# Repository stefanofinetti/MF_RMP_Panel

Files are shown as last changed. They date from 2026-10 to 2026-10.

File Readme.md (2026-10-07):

# Radio Management Panel (RMP)

An Airbus A319/320/321 Radio Management Panel for MobiFlight: a 3D-printed
front panel, keys and case, four boards, and two 6-digit frequency displays.
It runs on the **stock MobiFlight Mega firmware**: no custom firmware to
build or flash.

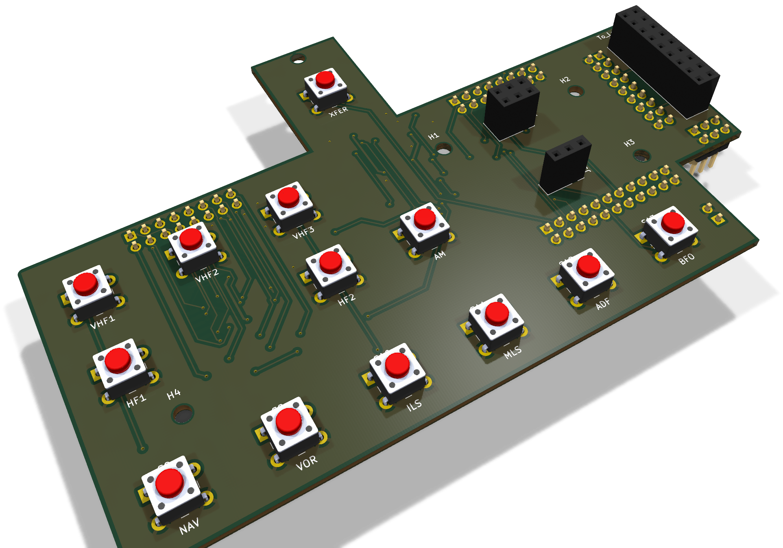
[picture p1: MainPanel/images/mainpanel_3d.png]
The MainPanel, rendered by KiCad


## V5 in short

V5 replaces the earlier version of this repository, a single board with
OLED displays and its own firmware. It is a new design:

* **four boards** instead of one: the logic, the keys and display drivers,
  the lighting, and a carrier for each frequency display;
* **7-segment displays** driven by two MAX7219, which MobiFlight drives
  natively as one LED module;
* **stock firmware**, MobiFlight Mega, core 3.1.4;
* the printed parts are drawn in **FreeCAD 1.1**.

**Status (October 2026):** the unit is built and in use. The boards in this
repository are the built ones, with one correction on the MainPanel (see
[Known issues](#known-issues)). All four are in KiCad 10, with ERC, DRC and
schematic parity clean. The printed parts are being reorganised.

## What is in the repository

| Folder | What it holds |
|---|---|
| [`BoardPanel/`](BoardPanel/README.md) | The logic board: ATmega2560, CH340G USB, 12 V and 5 V supply |
| [`MainPanel/`](MainPanel/README.md) | The keys, the two MAX7219, and the connectors to every other board |
| [`LedsPanel/`](LedsPanel/README.md) | The backlight and the thirteen key lights |
| [`7Segments/`](7Segments/README.md) | The carrier of one frequency display. Two are needed |
| `Libraries/` | The parts shared by the four boards: `RMP.kicad_sym`, `RMP.pretty` and the vendor 3D models in `3dmodels/` |
| `SF_RMP/` | `SF RMP.mfmc`, the MobiFlight board config |
| `3D FIles/` | The FreeCAD sources (`RMP_Panel.FCStd` is the whole assembly), the STL files, the B612 fonts of the legends. Being reorganised |

## The boards

```
 12 V jack ─► BoardPanel ─┬─ J4 ribbon ─► MainPanel J2 ─► J1 ─► LedsPanel (plugged in)
 USB-B     ─►             ├─ J5 ribbon ─► MainPanel J3   keys, encoders, ON/OFF
                          └─ J3 ribbon ─► MainPanel J9 ─┬─ J7 ribbon ─► 7Segments ACTIVE
                                                        └─ J8 ribbon ─► 7Segments STBY
```

| Board | PCB (mm) | What is on it |
|---|---|---|
| [BoardPanel](BoardPanel/README.md) | 110 × 55 | ATmega2560, CH340G, USB-B, 12 V jack, P78A05 5 V module, ISP header |
| [MainPanel](MainPanel/README.md) | 122 × 80 | 13 keys, 2 × MAX7219, encoder and switch connectors |
| [LedsPanel](LedsPanel/README.md) | 122 × 80 | 69 backlight LEDs with their PWM switch, 13 key lights |
| [7Segments](7Segments/README.md) × 2 | 51 × 20 | Two 3-digit common-cathode displays, MHz and kHz |

All four are two-layer, 1.6 mm boards, sized for hand soldering, with
values, polarity and pin 1 on the silkscreen.

## Building one

1. **Print** the panel, keys, case and supports from `3D FIles/`.
2. **Order the boards.** Run the Fabrication Toolkit plugin in each KiCad
   project for the Gerbers, BOM and positions. Order the 7Segments twice.
3. **Assemble** them. The board readmes list what to watch for.
4. **Cable them** as in the diagram above: straight ribbons, pin 1 to
   pin 1. The LedsPanel plugs straight into the MainPanel's J1.
5. **Burn the bootloader** once through the ISP header J2 of the BoardPanel,
   with JP1 on 2–3; then put JP1 back on 1–2. See the
   [BoardPanel readme](BoardPanel/README.md#burning-the-bootloader).
6. **Flash the MobiFlight Mega firmware** from the MobiFlight Connector,
   then load `SF_RMP/SF RMP.mfmc` and upload it to the board.
7. **Bind** the keys, lights, displays and encoders in your MobiFlight
   project.

The BoardPanel's logic runs from USB; the 12 V adapter feeds the backlight,
the displays and the fan.

## MobiFlight

Stock **MobiFlight Mega** firmware, module name `SF RMP`. The config in
`SF_RMP/SF RMP.mfmc` holds:

| Device | Type | Pins |
|---|---|---|
| `Display Freq` | LED module, MAX7219, 2 devices | DIN D23, CLK D22, CS D68. Connector 1 = STBY, connector 2 = ACTIVE |
| `Dimmer` | Output, PWM | D6, the backlight |
| `KHZ_Encoder` | Encoder | Left D27, right D25 |
| `MHZ_Encoder` | Encoder | Left D28, right D26 |
| `VHF1_LED` … `SEL_LED` | Outputs | A0–A12 (D54–D66): VHF1, VHF2, VHF3, HF1, HF2, AM, NAV, VOR, ILS, MLS, ADF, BFO, SEL |

| Key | Pin | Key | Pin | Key | Pin |
|---|---|---|---|---|---|
| XFER | D29 | HF2 | D36 | MLS | D31 |
| VHF1 | D39 | AM | D35 | ADF | D30 |
| VHF2 | D15 | NAV | D34 | BFO | D40 |
| VHF3 | D14 | VOR | D33 | ON/OFF | D41 |
| HF1 | D37 | ILS | D32 | | |

Each MAX7219 drives six digits; the decimal point after the MHz is set in
the project row of each display.

## Known issues

* **The first MainPanel had the two MAX7219 side by side instead of in a
  chain.** The files here are corrected. A board built from the first files
  needs two wires, described in the
  [MainPanel readme](MainPanel/README.md#boards-built-before-this-revision).
* **Two STL files are empty:** the white parts of the VHF1 and VHF3 keys.
  They will be re-exported from FreeCAD with the reorganisation of the
  printed parts.

## Software

* [KiCad](https://www.kicad.org/) 10. The files are saved by KiCad 10 and
  do not open in older versions
* [FreeCAD](https://www.freecad.org/) 1.1, to change the printed parts
* [MobiFlight](https://www.mobiflight.com/)

```bash
git clone https://github.com/stefanofinetti/MF_RMP_Panel.git
```

## License

This code and all the items are released under the GPLv3.0 license. Feel free
to use them as you wish, as long as you redistribute the source code.
A mention would be nice, though, if you use this work: I invested a good
many hours in it, just for the amazing MobiFlight community.

## Acknowledgements

This project couldn't have seen the light without the excellent work, and
kind support, of [GaGagu](https://github.com/gagagu) and
[ElRal](https://github.com/elral). Their work is amazing, so please have a
look at their repositories.

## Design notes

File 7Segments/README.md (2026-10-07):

# RMP 7Segments

The carrier of one frequency display: two 3-digit 7-segment displays,
MHz and kHz, side by side. **Two are needed**, one for ACTIVE and one for
STBY. Each sits in its printed display case and reaches the MainPanel
through a 16-pin ribbon.

* **PCB:** 51 × 20 mm, 2 layers, 1.6 mm, GND poured on both sides.
* **Fixing:** six M2 holes.
* **Parts:** 5: four socket strips for the displays on the top, one header
  on the bottom.
* **Status:** built and in use. ERC and schematic parity are clean; DRC
  reports only silkscreen clipped by the solder mask around J5.

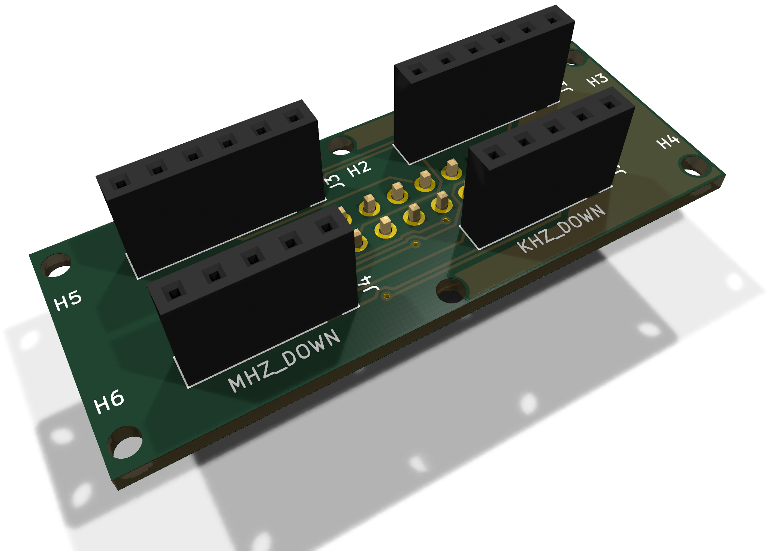
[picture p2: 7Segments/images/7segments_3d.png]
7Segments, 3D view


| Top: the display sockets | Bottom: J5 |
|---|---|
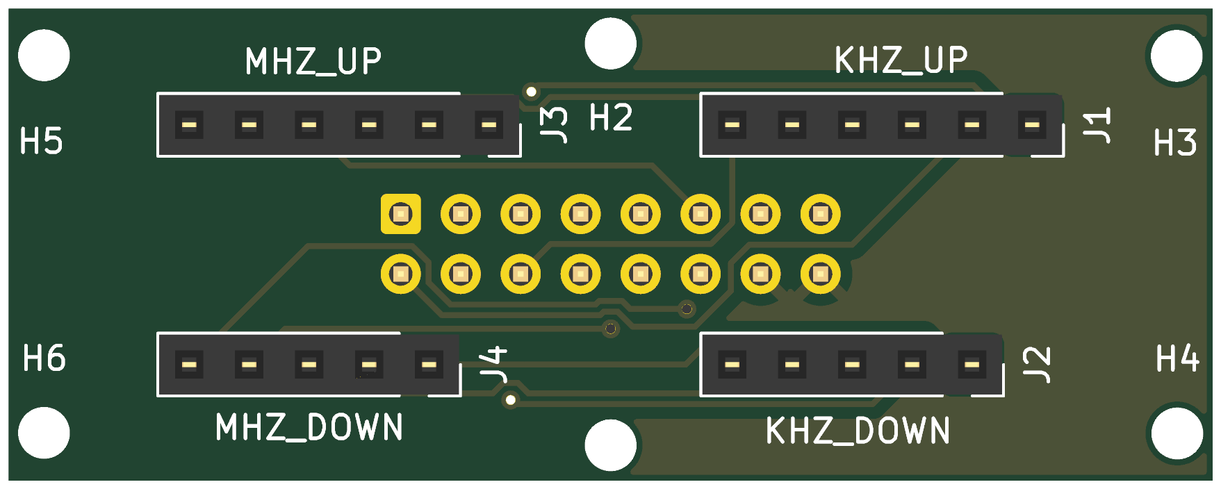
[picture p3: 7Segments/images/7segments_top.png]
7Segments, top
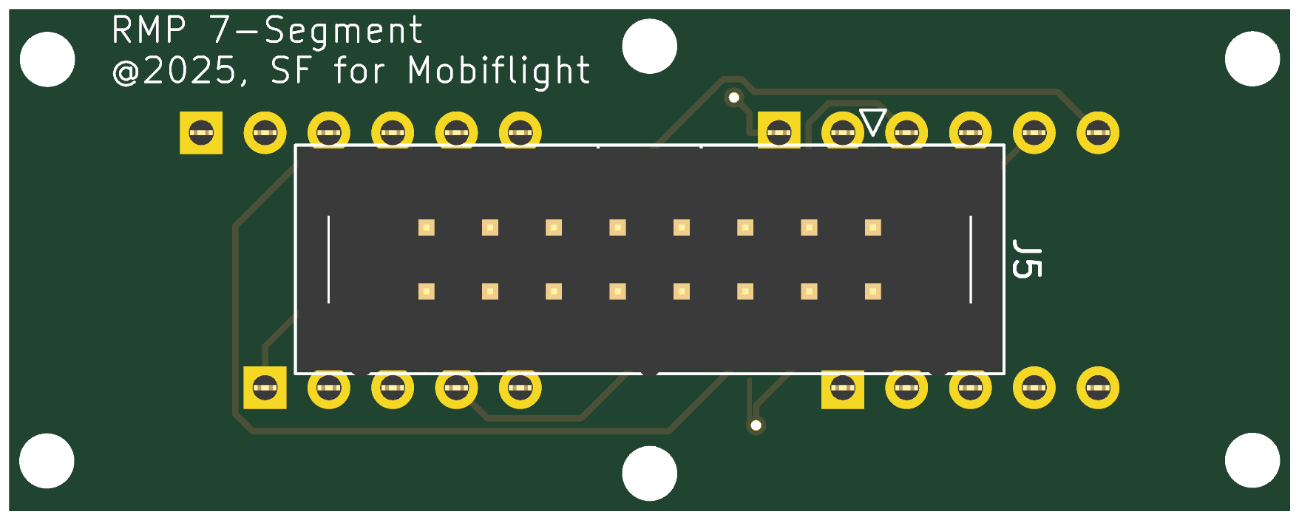
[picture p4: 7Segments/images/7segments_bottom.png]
7Segments, bottom
|  |  |

Rendered by KiCad from the board file. The bottom is seen from below, so it
is mirrored against the top.

## Connectors

| Ref | What | Notes |
|---|---|---|
| J1 / J2 | Socket strips 1 × 6 / 1 × 5 | kHz display, upper and lower row of pins |
| J3 / J4 | Socket strips 1 × 6 / 1 × 5 | MHz display, upper and lower row of pins |
| J5 | Shrouded IDC header 2 × 8, on the bottom | To MainPanel J7 (ACTIVE) or J8 (STBY), pin 1 to pin 1 |

**J5:** odd pins are the segments, 1 A, 3 B, 5 C, 7 D, 9 E, 11 F, 13 G,
15 the decimal point; even pins are the digits, 2 / 4 / 6 kHz 3 / 2 / 1,
8 / 10 / 12 MHz 3 / 2 / 1; 14 and 16 GND.

The displays must be **common cathode**: the MAX7219 sinks the digits and
drives the segments. The decimal point is wired on both displays; which digit
shows it is set in the MobiFlight project.

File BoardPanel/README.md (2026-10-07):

# RMP BoardPanel

The logic board of the RMP: the microcontroller, USB and power. It stands
upright on the printed support at the back of the case and reaches the
MainPanel through three ribbons.

* **PCB:** 110 × 55 mm, 2 layers, 1.6 mm, GND poured on both sides.
* **Fixing:** six M2 holes.
* **Parts:** 44, all on the top.
* **Status:** built and in use. ERC, DRC and schematic parity are clean.

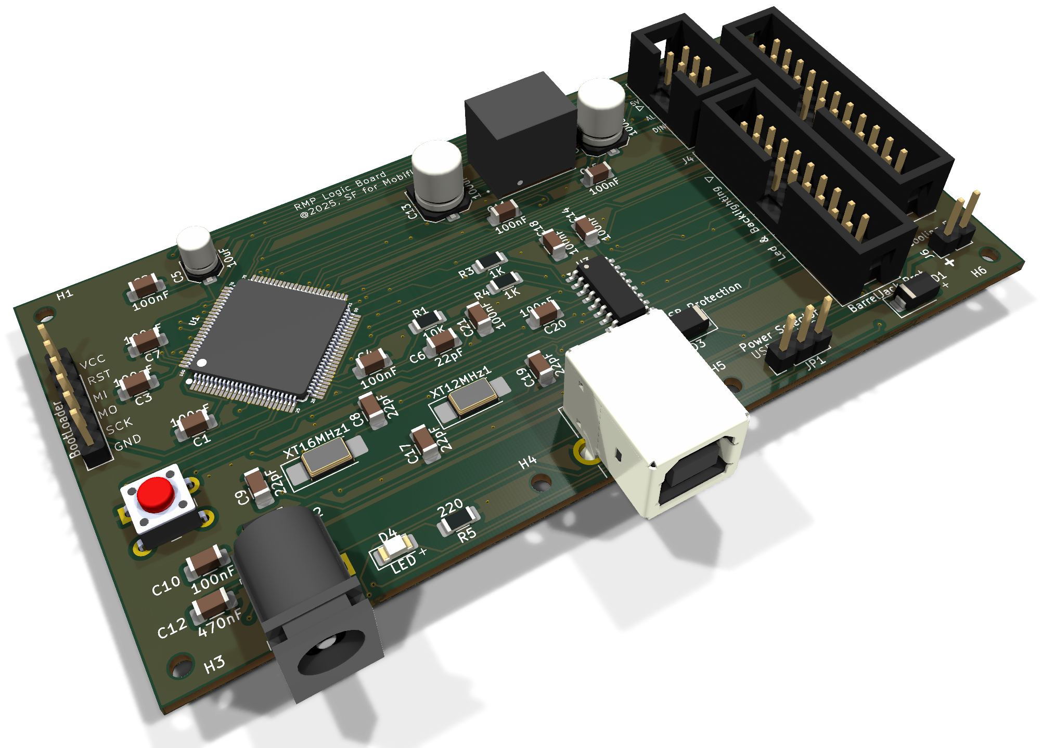
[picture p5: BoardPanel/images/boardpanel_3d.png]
BoardPanel, 3D view


| Top | Bottom |
|---|---|
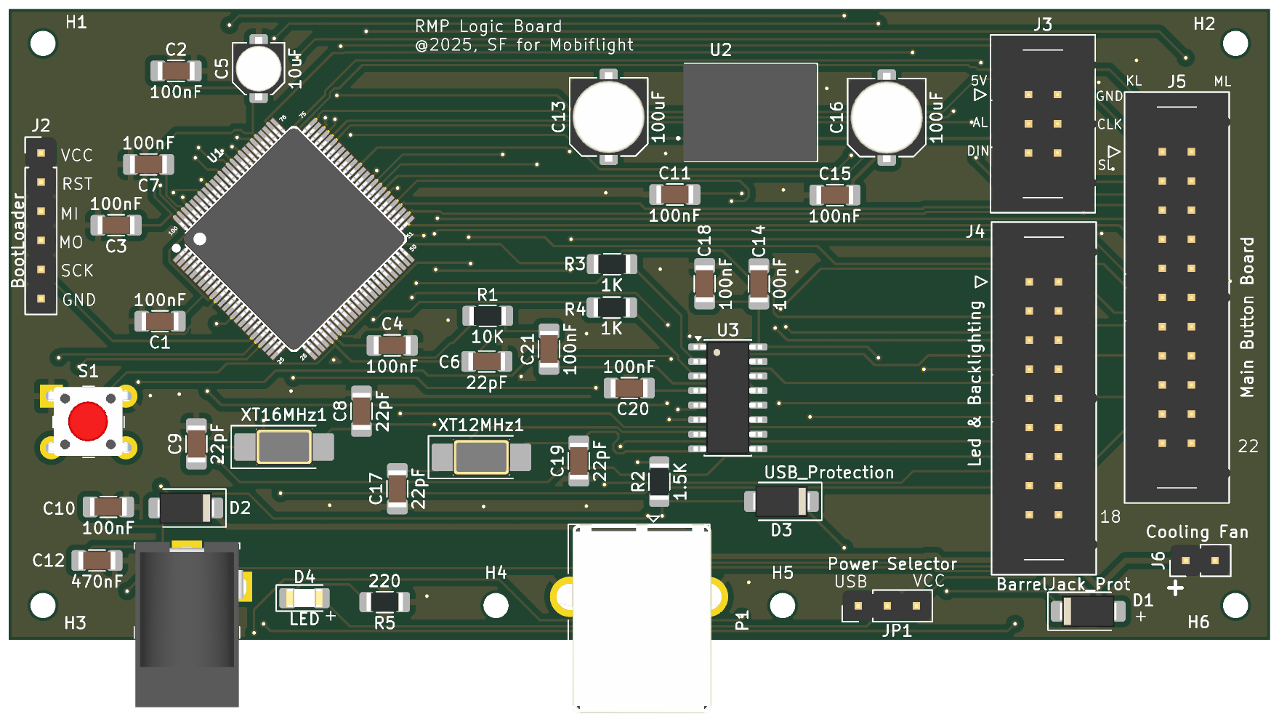
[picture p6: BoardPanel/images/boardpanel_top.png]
BoardPanel, top
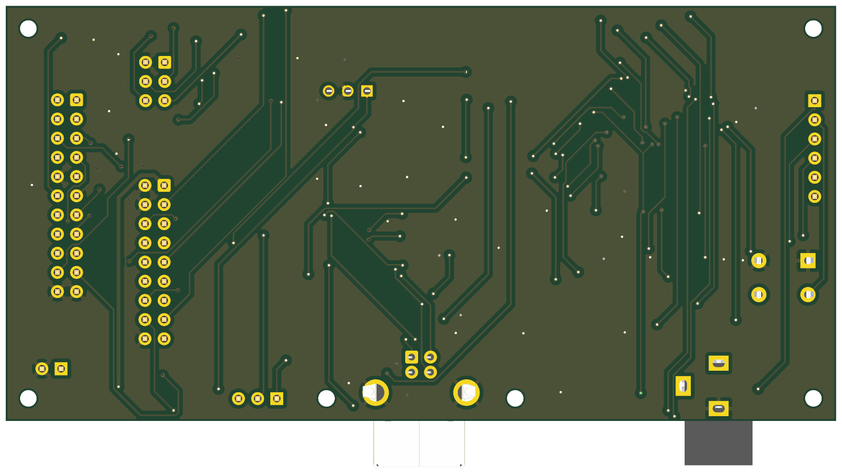
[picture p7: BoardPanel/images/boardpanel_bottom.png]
BoardPanel, bottom
|  |  |

Rendered by KiCad from the board file. The bottom is seen from below, so it
is mirrored against the top.

## What is on it

* **Microcontroller:** ATmega2560 (U1) with a 16 MHz crystal, and a CH340G
  (U3, 12 MHz crystal) for USB. MobiFlight sees it as a Mega.
* **Power:**
  * 12 V from the barrel jack J1, through D2, is the `+12V` rail: the
    backlight (J4) and the fan (J6).
  * From `+12V`, through D1, a P78A05 switching module (U2) makes the 5 V
    for the two MAX7219 only (J3).
  * The ATmega and the CH340G run from USB, through D3 and JP1. The
    displays and the backlight need the 12 V; the logic does not.

## Connectors and settings

| Ref | What | Notes |
|---|---|---|
| J1 | 12 V in, 5.5 × 2.1 barrel jack | Pin 1 `+`, through D2 |
| P1 | USB-B | To the computer |
| J2 | ISP header, 1 × 6 | 1 VCC, 2 RESET, 3 MISO, 4 MOSI, 5 SCK, 6 GND |
| JP1 | Power selector | 1–2: MCU from USB (normal use). 2–3: MCU from J2's VCC only, to burn the bootloader |
| J3 | Displays, IDC 2 × 3 | To MainPanel J9 |
| J4 | LEDs and backlight, IDC 2 × 9 | To MainPanel J2 |
| J5 | Buttons and encoders, IDC 2 × 11 | To MainPanel J3 |
| J6 | Cooling fan, 2 pins | `+12V` and GND, for a 12 V fan |
| S1 | Reset | |

Every ribbon is straight, pin 1 to pin 1.

**J3, displays:** 1 `+5V`, 2 GND, 3 D67 (marked `AL`, no longer used, see
the MainPanel), 4 CLK (D22), 5 DIN (D23), 6 LOAD (D68).

**J4, LEDs and backlight:** 1 `+12V`, 2 GND, 3 backlight PWM (D6), 4 GND,
5–17 the thirteen key LEDs (A0–A12, in the order VHF1, VHF2, VHF3, HF1,
HF2, AM, NAV, VOR, ILS, MLS, ADF, BFO, SEL), 18 GND.

**J5, buttons and encoders:** see the pin map in the
[main readme](../Readme.md#mobiflight).

## Burning the bootloader

A new ATmega2560 is blank. Put JP1 on 2–3, so the programmer powers the
MCU alone through J2, and burn the Arduino Mega bootloader once. Then put
JP1 back on 1–2. From then on the board is flashed over USB like a Mega.

## Assembly notes

* Everything is sized for hand soldering: 1206 passives, 5 × 3.2 mm
  crystals.
* Values, polarity and pin 1 are on the silkscreen.

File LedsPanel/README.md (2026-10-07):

# RMP LedsPanel

The lighting board, right behind the front panel: the backlight of the
legends and the thirteen key lights. It plugs straight into the MainPanel.

* **PCB:** 122 × 80 mm, 2 layers, 1.6 mm, GND poured on both sides.
* **Fixing:** six M2.5 holes.
* **Parts:** 113. The backlight resistors and J1 are on the bottom.
* **Status:** built and in use. ERC, DRC and schematic parity are clean.

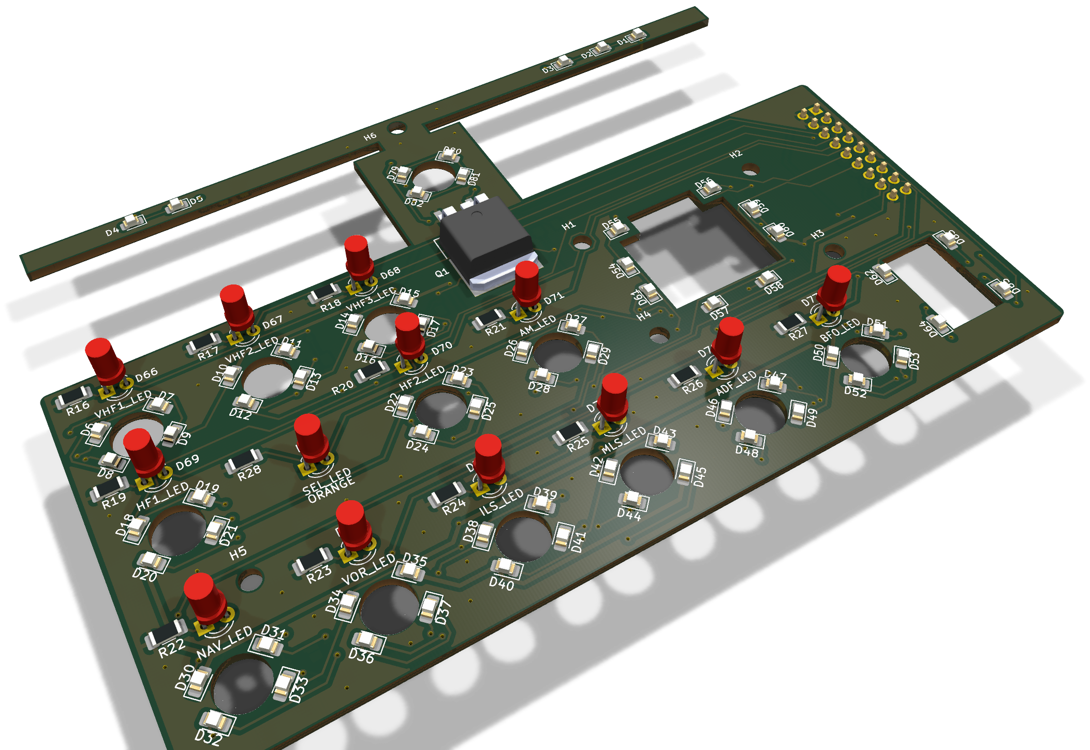
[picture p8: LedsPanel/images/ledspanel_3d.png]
LedsPanel, 3D view


| Top: the panel side | Bottom: resistors and J1 |
|---|---|
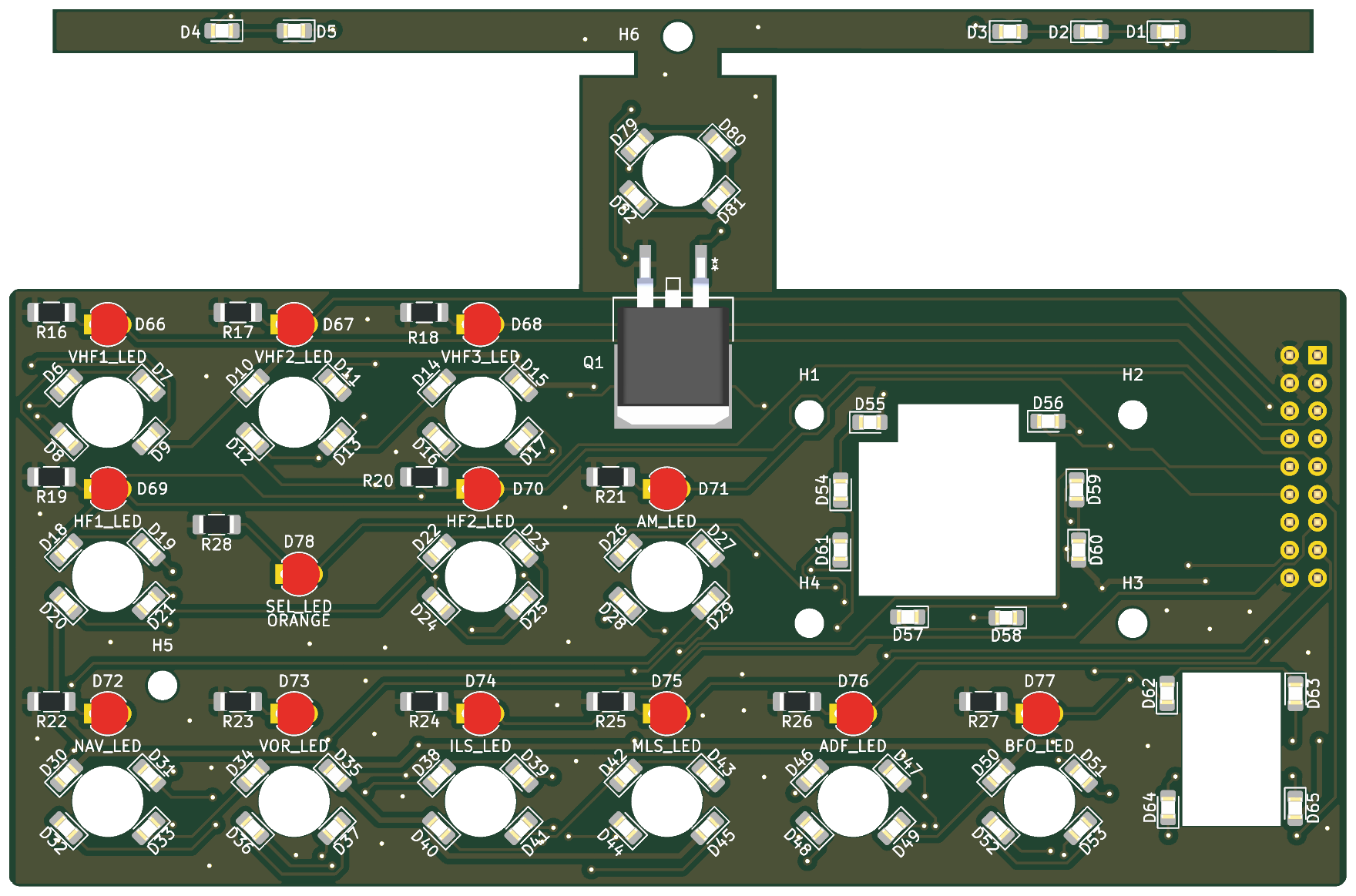
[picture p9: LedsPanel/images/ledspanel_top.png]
LedsPanel, top
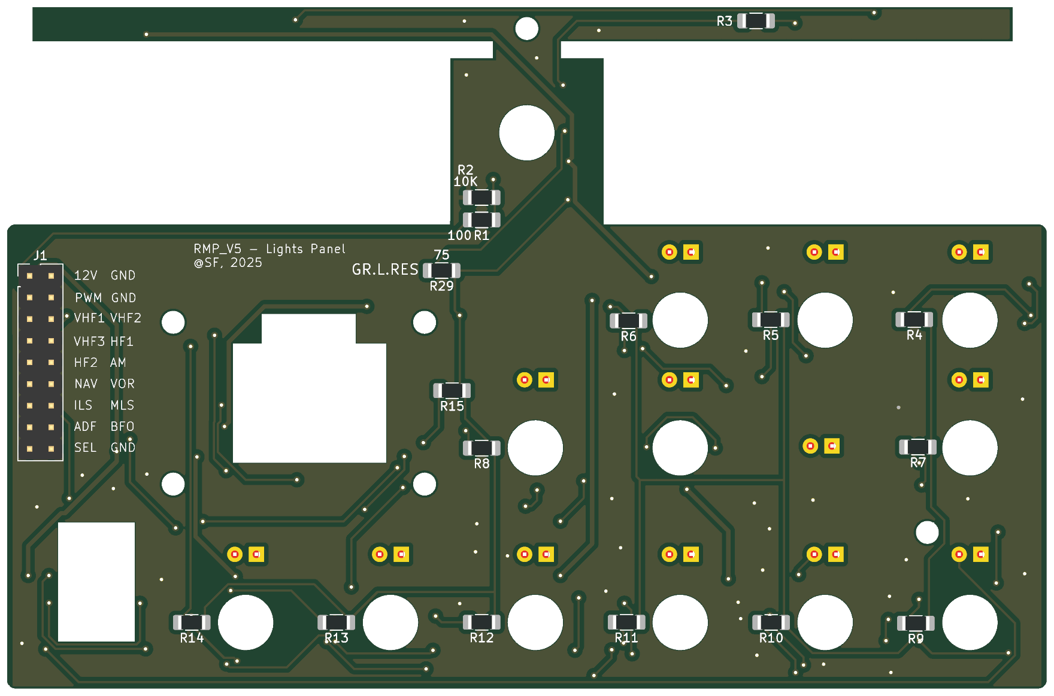
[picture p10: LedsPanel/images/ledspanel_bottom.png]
LedsPanel, bottom
|  |  |

Rendered by KiCad from the board file. The bottom is seen from below, so it
is mirrored against the top.

## Connector

| Ref | What | Goes to |
|---|---|---|
| J1 | Header 2 × 9, on the bottom | Plugs into the MainPanel's J1. 1 `+12V`, 2 / 4 / 18 GND, 3 backlight PWM, 5–17 the key LEDs |

## Backlight

69 orange 0805 LEDs, chosen to match the brightness of the Airbus panels,
on `+12V`:

* D1–D65: thirteen strings of five, each with its 75 Ω (R3–R15);
* D79–D82: one string of four, with R29, 75 Ω.

Every string returns to `LED_RETURN`, switched to GND by Q1, an IRLZ44N
(logic-level N-MOSFET, D2PAK). Its gate is driven by the backlight PWM
(D6) through R1, 100 Ω, with R2, 10 kΩ, pulling it down: with the PWM at 0
or the MobiFlight Connector closed, the backlight is off.

The string of four has one LED fewer across the same 75 Ω, so it carries
more current than the strings of five.

## Key lights

D66–D78, 3 mm flat-top LEDs, one in each key. The anode is driven straight
by the MCU pin through J1; the cathode goes to GND through 200 Ω
(R16–R28).

| D66 | D67 | D68 | D69 | D70 | D71 | D72 | D73 | D74 | D75 | D76 | D77 | D78 |
|---|---|---|---|---|---|---|---|---|---|---|---|---|
| VHF1 | VHF2 | VHF3 | HF1 | HF2 | AM | NAV | VOR | ILS | MLS | ADF | BFO | SEL |

The key lights are not dimmed. On the aircraft they follow the ANN LT
switch, apart from the backlight; a separate dimmer for them is being
considered.

## Assembly notes

* Everything is sized for hand soldering: 0805 LEDs, 1206 resistors.
* LED polarity, values and pin 1 are on the silkscreen.

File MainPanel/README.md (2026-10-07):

# RMP MainPanel

The board behind the front panel: the thirteen keys, the two MAX7219 that
drive the frequency displays, and the connectors for the encoders, the
ON/OFF switch, the LedsPanel and the two display boards. It reaches the
BoardPanel through three ribbons.

* **PCB:** 122 × 80 mm, 2 layers, 1.6 mm, GND poured on both sides.
* **Fixing:** five 2.5 mm holes.
* **Parts:** 30. On the top: the keys, J1 for the LedsPanel and the two
  encoder sockets. On the bottom: the two MAX7219 with their passives, and
  the headers to the BoardPanel, the display boards and the ON/OFF switch.
* **Status:** the display chain is corrected in this revision (see below)
  and rerouted. ERC, DRC and schematic parity are clean. The corrected
  board has not been ordered yet.

MainPanel, 3D view

| Top: the keys | Bottom: drivers and connectors |
|---|---|
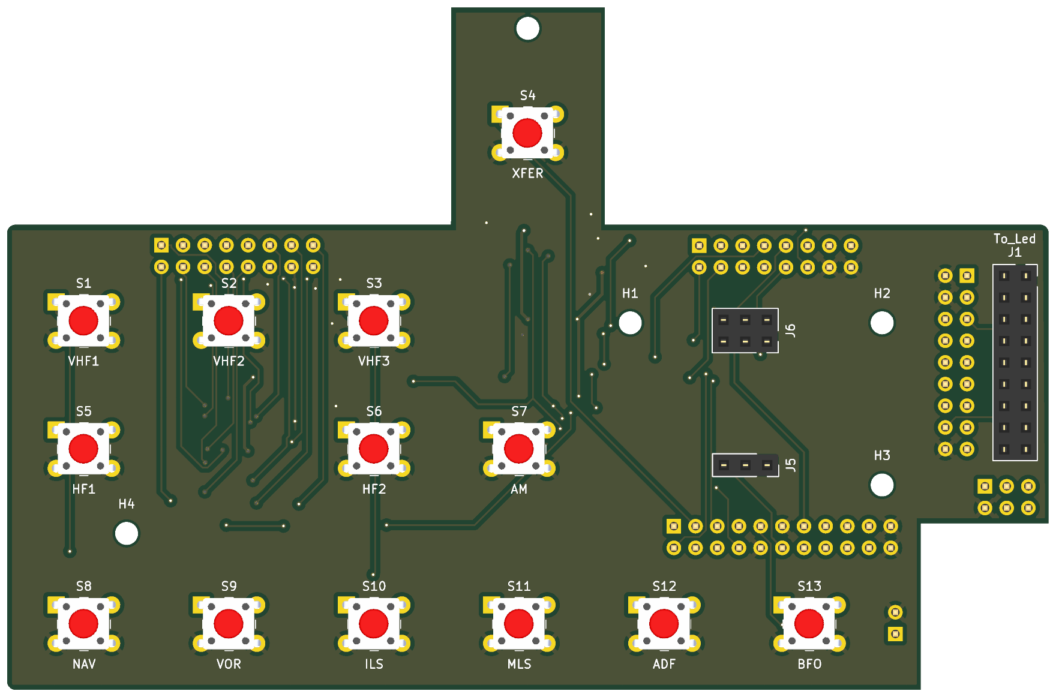
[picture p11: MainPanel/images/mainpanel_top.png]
MainPanel, top
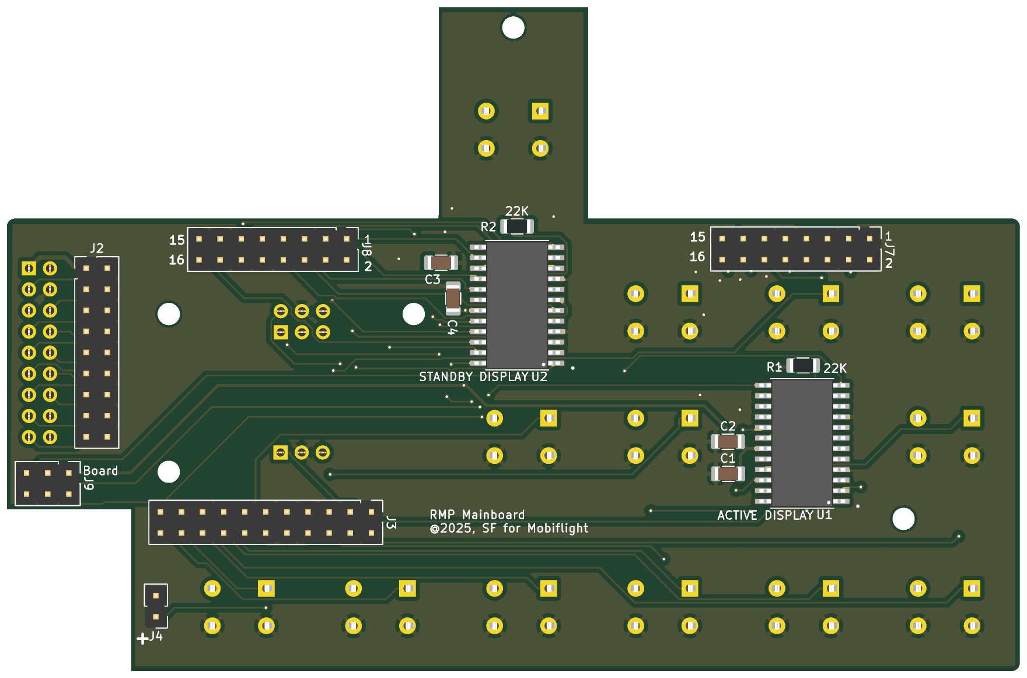
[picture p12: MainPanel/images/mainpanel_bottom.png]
MainPanel, bottom
|  |  |

Rendered by KiCad from the board file. The bottom is seen from below, so it
is mirrored against the top.

## Connectors

| Ref | What | Goes to |
|---|---|---|
| J1 | Socket 2 × 9 | The LedsPanel's J1 plugs in here. Same pins as J2 |
| J2 | Header 2 × 9 | BoardPanel J4: backlight, PWM, the thirteen key LEDs |
| J3 | Header 2 × 11 | BoardPanel J5: keys, encoders, ON/OFF |
| J9 | Header 2 × 3 | BoardPanel J3: the display bus |
| J7 | Header 2 × 8 | ACTIVE display board, its J5 |
| J8 | Header 2 × 8 | STBY display board, its J5 |
| J5 | Socket 1 × 3 | kHz encoder: 1 `RADIO_KHZ_LEFT` (D25), 2 GND, 3 `RADIO_KHZ_RIGHT` (D27) |
| J6 | Socket 2 × 3 | MHz encoder: 2 `RADIO_MHZ_LEFT` (D26), 4 GND, 6 `RADIO_MHZ_RIGHT` (D28). Pins 1, 3, 5 are not connected |
| J4 | Header 1 × 2 | ON/OFF switch: 1 to D41, 2 GND |

Every connection is pin 1 to pin 1. The pinouts of J2, J3 and J9 are in
the [BoardPanel readme](../BoardPanel/README.md#connectors-and-settings).

## The keys

S1–S13, 6 × 6 mm tactile switches, each between its input and GND. The
MCU's internal pull-ups hold the inputs high.

| S1 | S2 | S3 | S4 | S5 | S6 | S7 | S8 | S9 | S10 | S11 | S12 | S13 |
|---|---|---|---|---|---|---|---|---|---|---|---|---|
| VHF1 | VHF2 | VHF3 | XFER | HF1 | HF2 | AM | NAV | VOR | ILS | MLS | ADF | BFO |

## The displays

Two MAX7219 in one chain, as MobiFlight expects for one LED module of two
devices:

```
D23 (DIN) ─► U2 STBY ─► DOUT ─► U1 ACTIVE
D22 (CLK) ─► U1 and U2
D68 (LOAD) ─► U1 and U2
```

U2 is the first device in the chain, so in MobiFlight connector 1 is the
standby frequency and connector 2 the active one. Each chip drives six
digits, three for MHz and three for kHz, through J7 / J8 to its display
board. R1 and R2 (22 kΩ) on `ISET` set the segment current; C1–C4 decouple
the two chips.

### Boards built before this revision

The first MainPanel had the two chips side by side on D23, with a LOAD
each (D67 for the Active, D68 for the Standby), and nothing on either
DOUT. That board works only with two hand-soldered wires, on the bottom:

1. pin 12 (LOAD) of U1 to pin 12 of U2;
2. pin 24 (DOUT) of U2 to pin 1 (DIN) of U1.

In the production files of that board, U1's pin 1 is also tied to D23 by
copper, which with the second wire gives it two drivers. If the Active
display shows the odd wrong segment now and then, check with the power off
for continuity between pin 1 of U1 and pin 1 of U2. If there is, cut the
track close to U1 pin 1.

## Assembly notes

* Everything is sized for hand soldering: 1206 passives, SOIC-24W chips.
* Values, polarity and pin 1 are on the silkscreen.

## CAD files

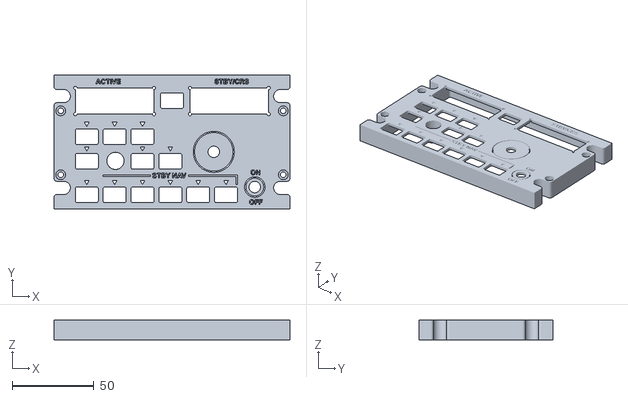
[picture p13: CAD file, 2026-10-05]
3D FIles/V5.1/RMP_Panel-Main Panel.stl
144.0 x 82.0 x 12.0

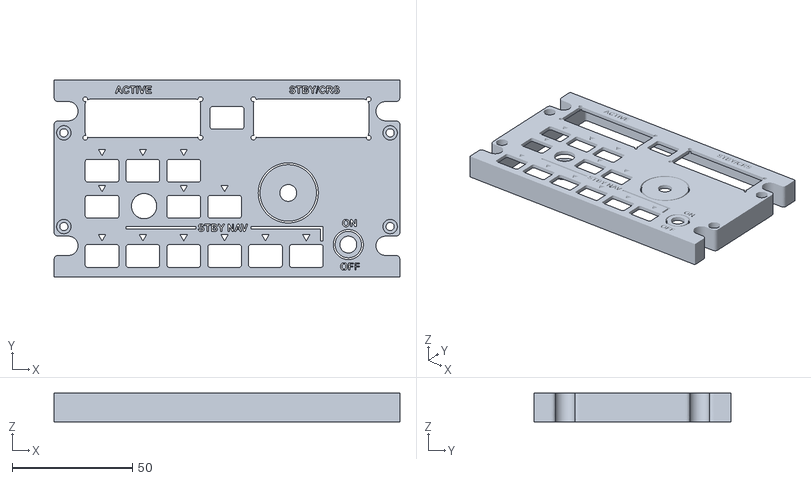
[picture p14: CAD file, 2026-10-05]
3D FIles/RMP_Panel-Main Panel.stl
144.0 x 82.0 x 12.0

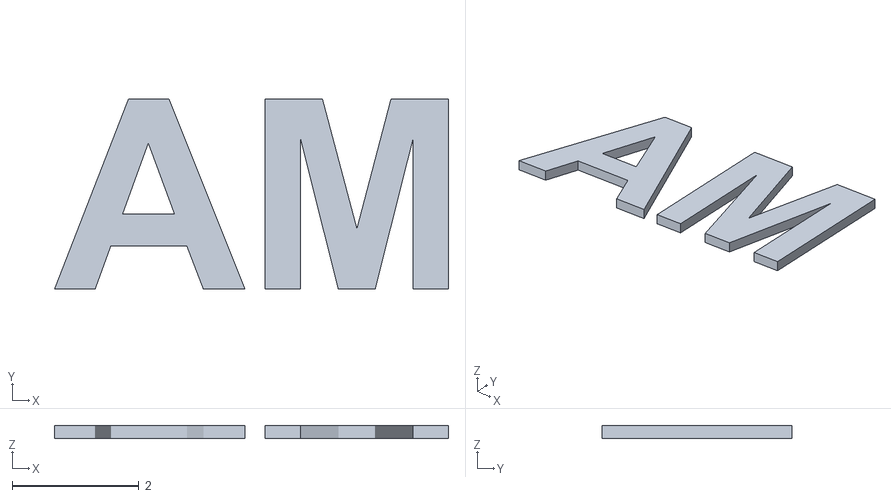
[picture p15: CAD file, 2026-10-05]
3D FIles/Buttons/RMP_Button-AM WhiteParts.stl
6.22 x 3.00 x 0.2

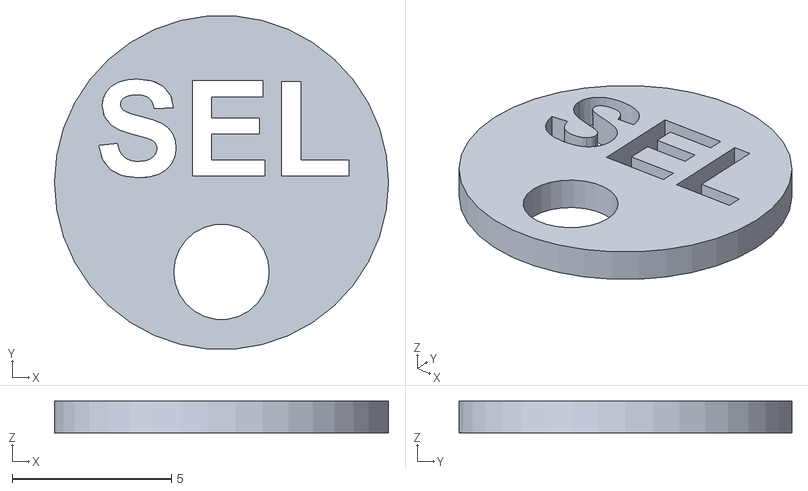
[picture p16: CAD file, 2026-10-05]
3D FIles/RMP_Panel-BlackElements.stl
10.5 x 10.5 x 1.00

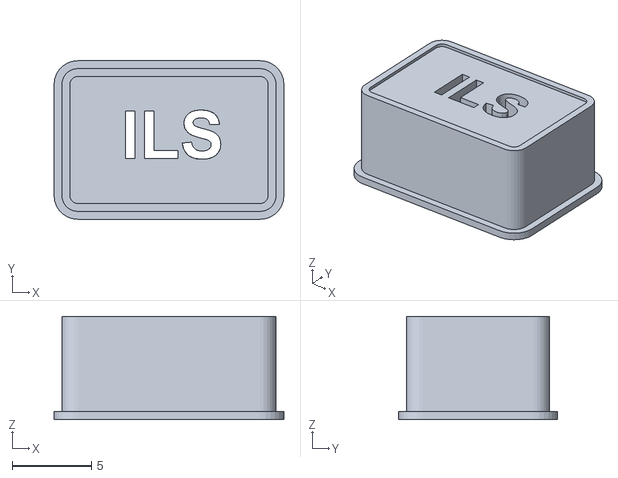
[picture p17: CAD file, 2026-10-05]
3D FIles/Buttons/RMP_Button-ILS Black Parts.stl
14.5 x 10.0 x 6.50

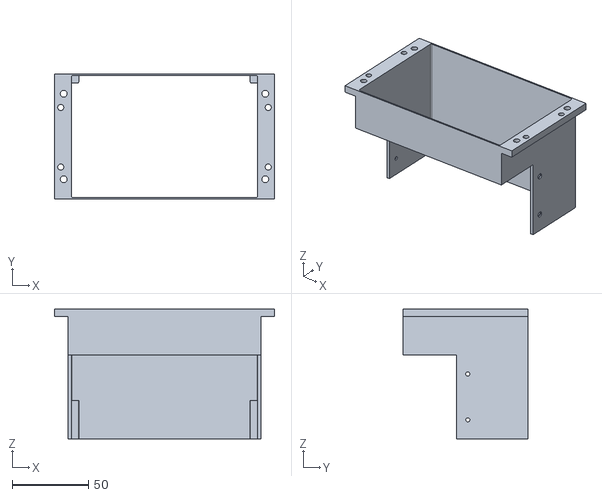
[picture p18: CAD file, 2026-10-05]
3D FIles/RMP_Panel-RMP Case.stl
144.0 x 82.0 x 85.0

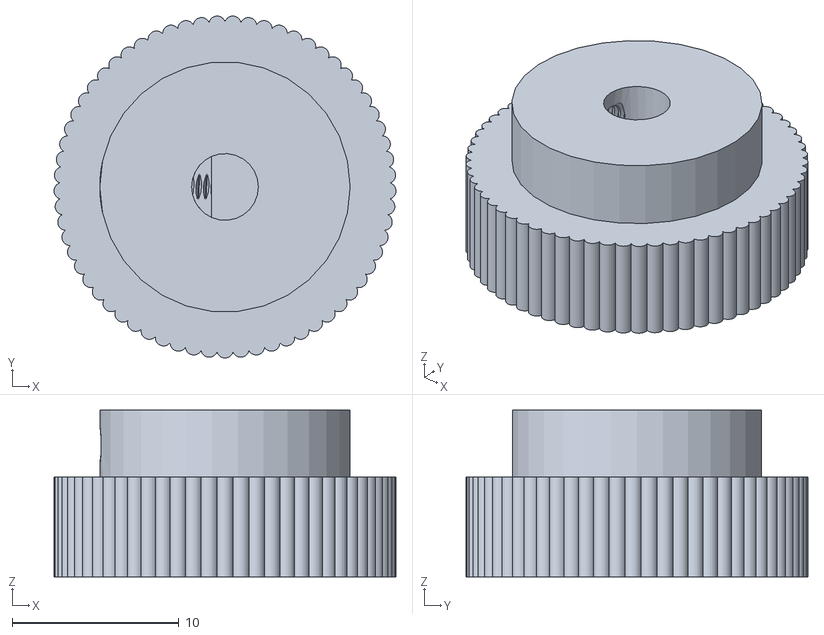
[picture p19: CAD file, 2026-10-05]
3D FIles/V5.1/RMP_Knob-UpperCircle_MHz.stl
20.5 x 20.5 x 10.0

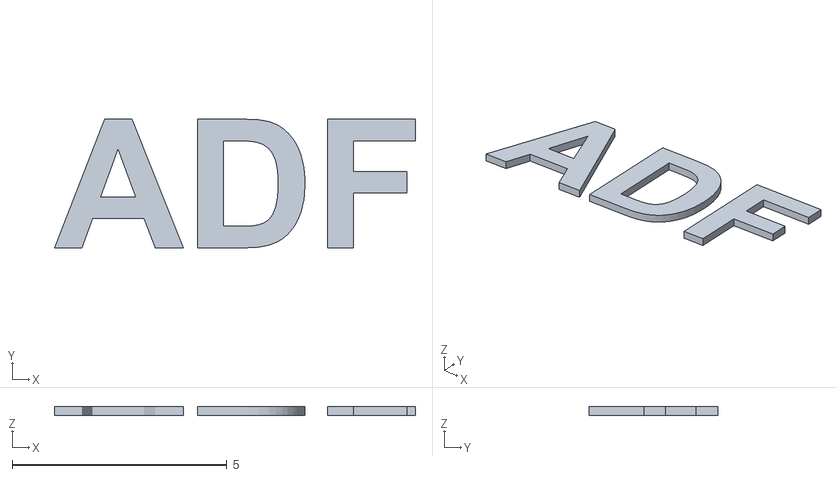
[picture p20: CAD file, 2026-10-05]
3D FIles/Buttons/RMP_Button- ADF White Parts.stl
8.42 x 3.00 x 0.2

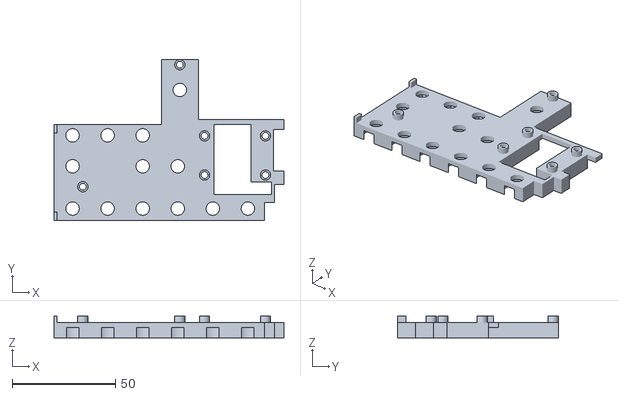
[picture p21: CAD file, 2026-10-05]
3D FIles/RMP_Panel-PCB Separator.stl
111.5 x 78.0 x 10.5

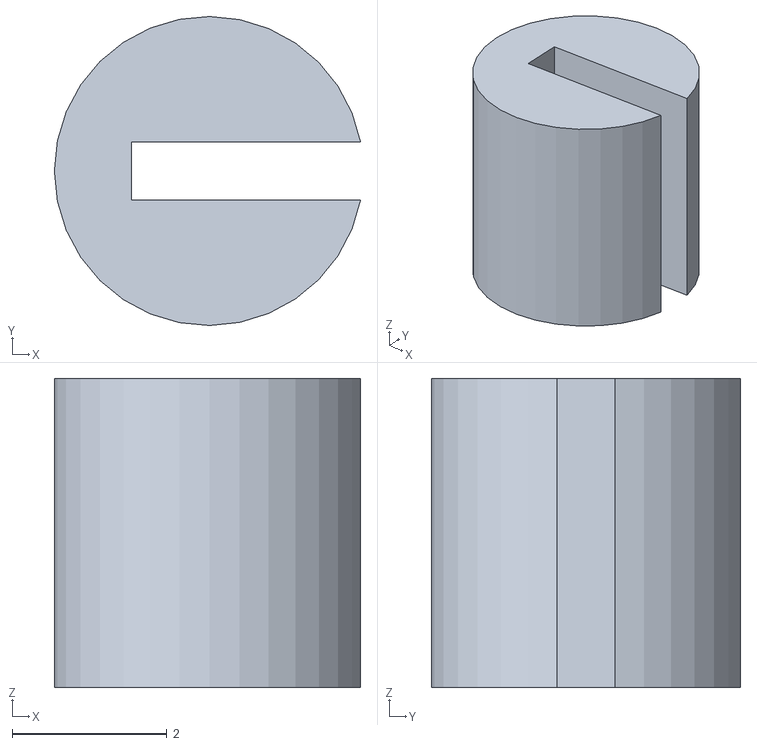
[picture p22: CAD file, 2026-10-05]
3D FIles/V5.1/CopriLed-CopriLed.stl
3.96 x 4.00 x 4.00

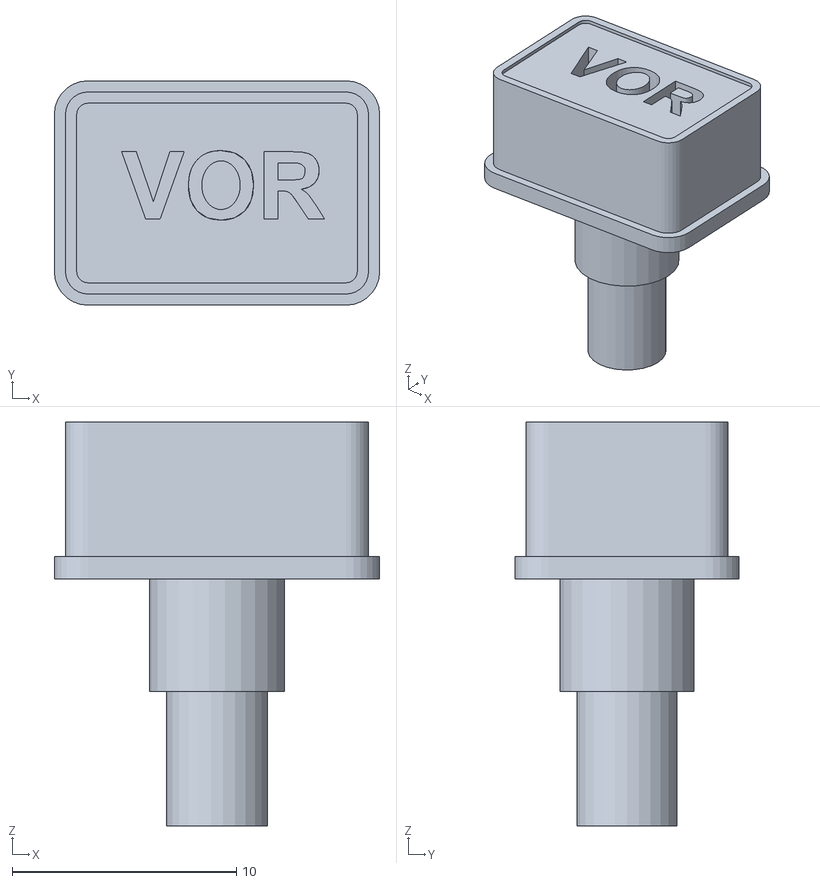
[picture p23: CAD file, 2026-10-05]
3D FIles/Buttons/RMP_Button- VOR Black Parts.stl
14.5 x 10.0 x 18.0

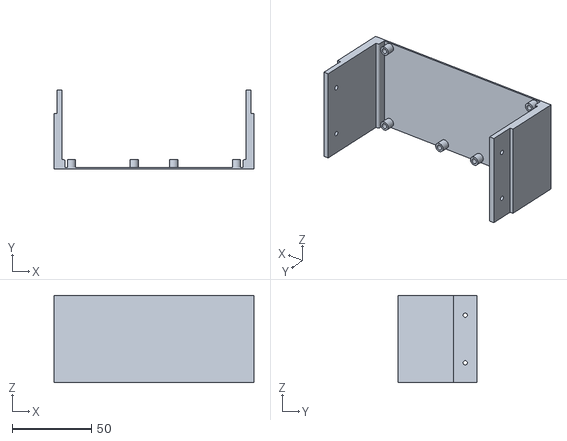
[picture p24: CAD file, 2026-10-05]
3D FIles/RMP_Panel-ArduinoSupport.stl
126.0 x 50.0 x 55.0

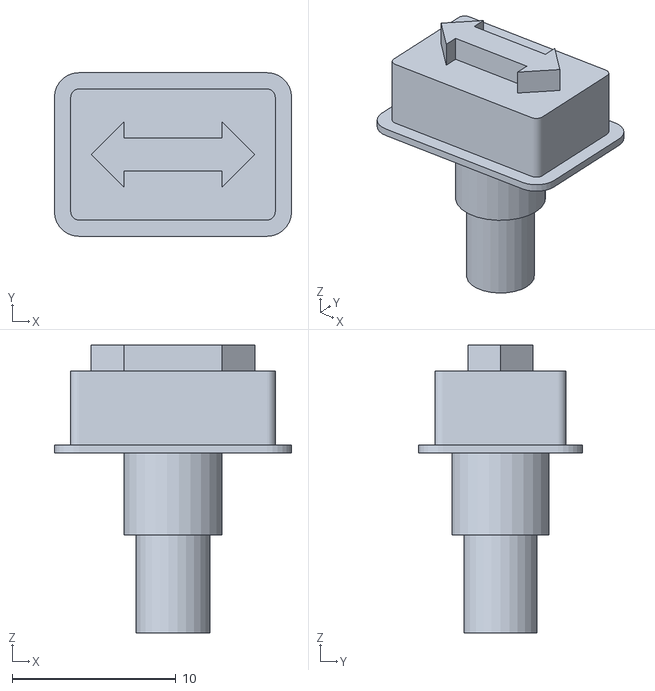
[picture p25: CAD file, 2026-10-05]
3D FIles/Buttons/RMP_Button-XFER Transparent Parts.stl
14.5 x 10.0 x 17.6

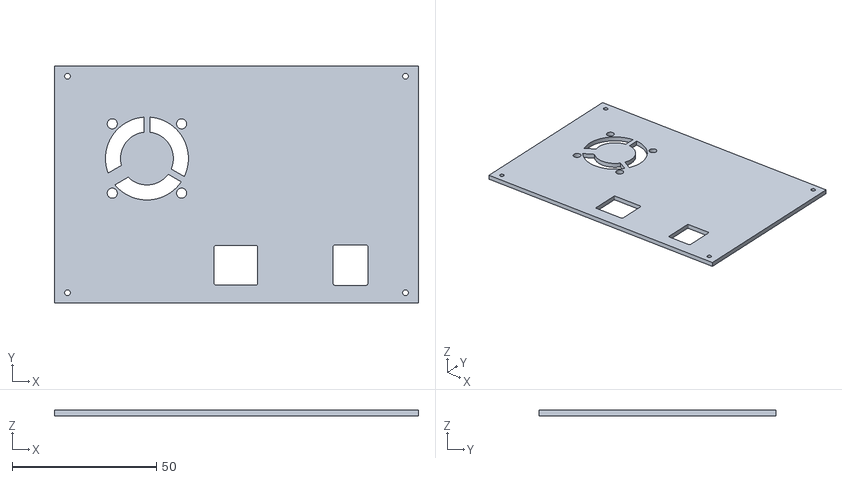
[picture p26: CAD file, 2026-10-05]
3D FIles/RMP_Panel-RMP Bottom (USB and power holes).stl
126.0 x 82.0 x 2.00

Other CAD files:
3D FIles/V5.1/RMP_Panel-Base.stl
3D FIles/V5.1/CopriLed-CopriLed-1.5mm.stl
3D FIles/Buttons/RMP_Button- VOR Transparent Parts.stl
3D FIles/Buttons/RMP_Button- ADF Black Parts.stl
3D FIles/Buttons/RMP_Button- ADF Transparent Parts.stl
3D FIles/Buttons/RMP_Button- BFO Black Parts.stl
3D FIles/Buttons/RMP_Button- BFO Transparent Parts.stl
3D FIles/Buttons/RMP_Button- BFO White Parts.stl
3D FIles/Buttons/RMP_Button- VOR White Parts.stl
3D FIles/Buttons/RMP_Button-AM Black Parts.stl
3D FIles/Buttons/RMP_Button-AM Transparent Parts.stl
3D FIles/Buttons/RMP_Button-HF1 Black Parts.stl
3D FIles/Buttons/RMP_Button-HF1 Transparent Parts.stl
3D FIles/Buttons/RMP_Button-HF1 WhiteParts.stl
3D FIles/Buttons/RMP_Button-HF2 Black Parts.stl
3D FIles/Buttons/RMP_Button-HF2 TransparentParts.stl
3D FIles/Buttons/RMP_Button-HF2 White Parts.stl
3D FIles/Buttons/RMP_Button-ILS Transparent Parts.stl
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

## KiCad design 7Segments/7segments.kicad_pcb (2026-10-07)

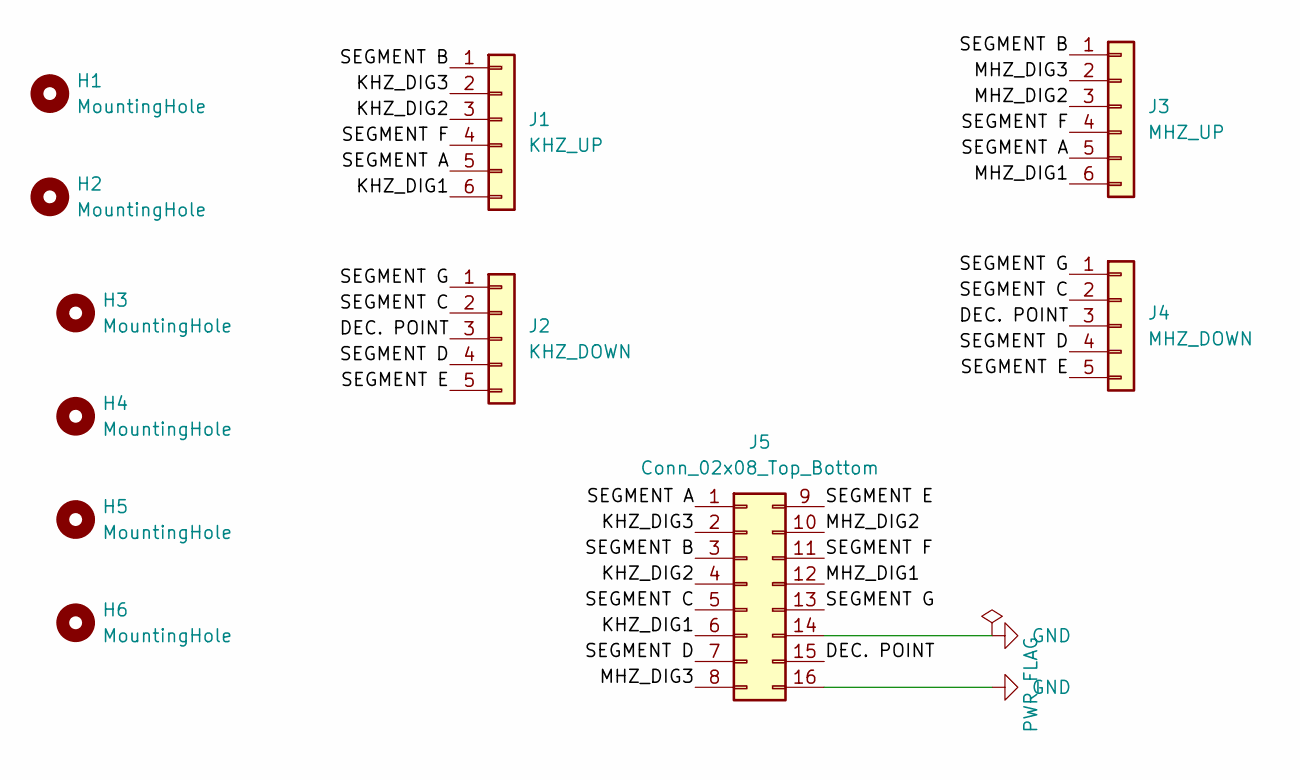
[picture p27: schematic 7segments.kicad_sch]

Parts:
H1, H2, H3, H4, H5, H6: MountingHole; MountingHole_2.2mm_M2
J1: KHZ_UP; PinSocket_1x06_P2.54mm_Vertical
J2: KHZ_DOWN; PinSocket_1x05_P2.54mm_Vertical
J3: MHZ_UP; PinSocket_1x06_P2.54mm_Vertical
J4: MHZ_DOWN; PinSocket_1x05_P2.54mm_Vertical
J5: Conn_02x08_Top_Bottom; IDC-Header_2x08_P2.54mm_Vertical

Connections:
/DEC. POINT: J2.3, J4.3, J5.15
/KHZ_DIG1: J1.6, J5.6
/KHZ_DIG2: J1.3, J5.4
/KHZ_DIG3: J1.2, J5.2
/MHZ_DIG1: J3.6, J5.12
/MHZ_DIG2: J3.3, J5.10
/MHZ_DIG3: J3.2, J5.8
/SEGMENT A: J1.5, J3.5, J5.1
/SEGMENT B: J1.1, J3.1, J5.3
/SEGMENT C: J2.2, J4.2, J5.5
/SEGMENT D: J2.4, J4.4, J5.7
/SEGMENT E: J2.5, J4.5, J5.9
/SEGMENT F: J1.4, J3.4, J5.11
/SEGMENT G: J2.1, J4.1, J5.13
GND: J5.14, J5.16

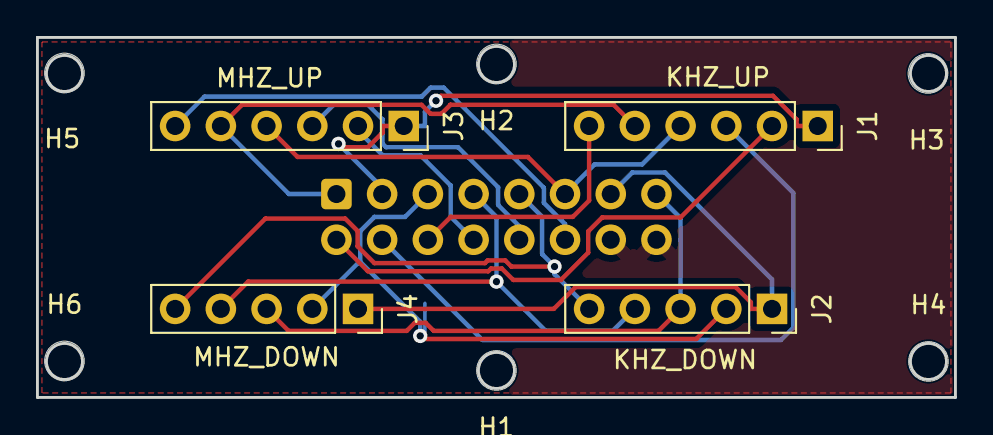
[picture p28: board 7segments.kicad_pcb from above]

Board: 2 copper layers, 51.0 x 20.0 mm, 11 parts (1 on the bottom side), 15 nets.

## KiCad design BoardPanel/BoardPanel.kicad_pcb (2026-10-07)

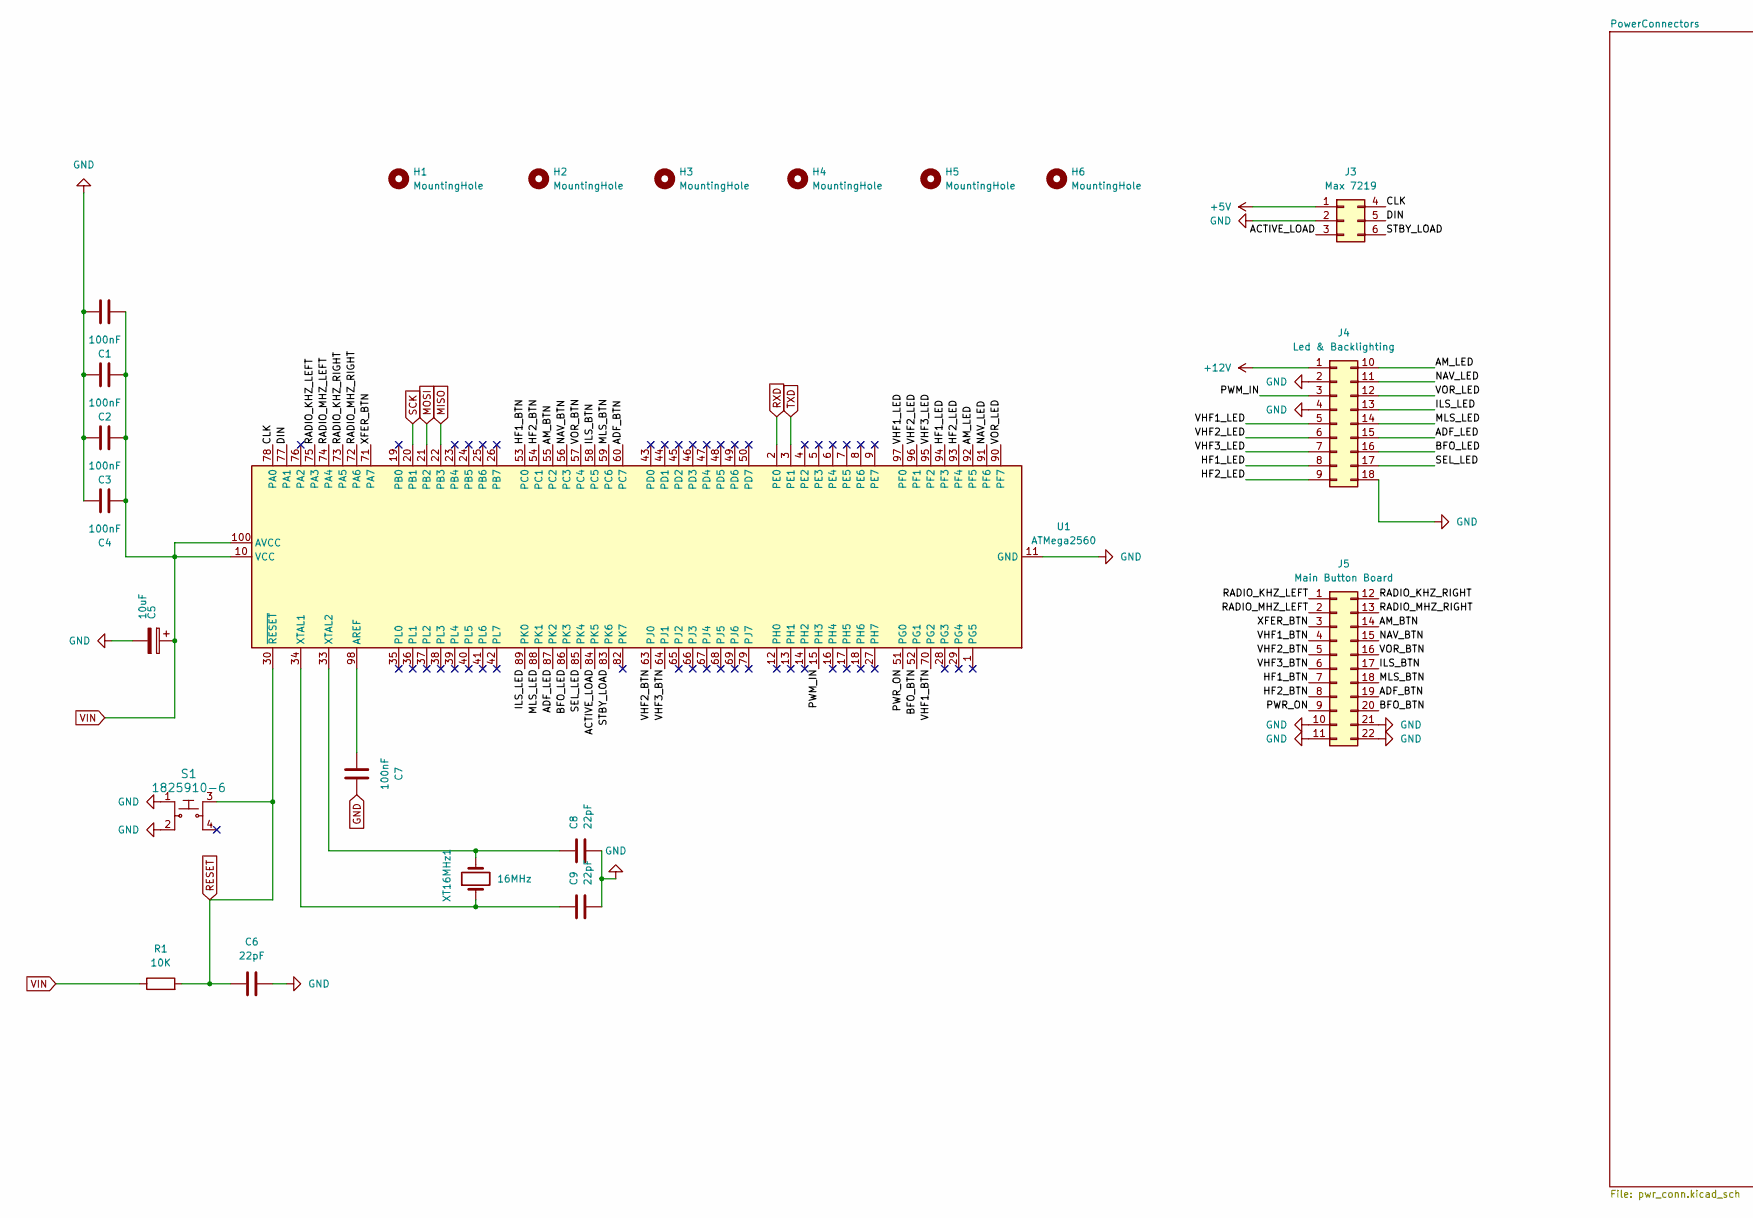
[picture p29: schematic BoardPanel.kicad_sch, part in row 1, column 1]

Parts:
C1, C2, C3, C4, C7: 100nF; C_1206_3216Metric_Pad1.33x1.80mm_HandSolder
C5: 10uF; C_Elec_4x5.4
C6, C8, C9: 22pF; C_1206_3216Metric_Pad1.33x1.80mm_HandSolder
H1, H2, H3, H4, H5, H6: MountingHole; MountingHole_2.2mm_M2_DIN965
J3: Max 7219; IDC-Header_2x03_P2.54mm_Vertical
J4: Led & Backlighting; IDC-Header_2x09_P2.54mm_Vertical
J5: Main Button Board; IDC-Header_2x11_P2.54mm_Vertical
R1: 10K; R_1206_3216Metric_Pad1.30x1.75mm_HandSolder
S1: 1825910-6; Switch_Tactile_THT_6x6mm_MJTP1230; MPN 1825910-6; Digi-Key_PN 450-1650-ND
U1: ATMega2560; TQFP100-0.5-14X14MM
XT16MHz1: 16MHz; Crystal_SMD_5032-2Pin_5.0x3.2mm_HandSoldering

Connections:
+5V: J3.1; also elsewhere on the board
+12V: J4.1; also elsewhere on the board
/ACTIVE_LOAD: J3.3, U1.84 (PK5)
/ADF_BTN: J5.19, U1.60 (PC7)
/ADF_LED: J4.15, U1.87 (PK2)
/AM_BTN: J5.14, U1.55 (PC2)
/AM_LED: J4.10, U1.92 (PF5)
/BFO_BTN: J5.20, U1.52 (PG1)
/BFO_LED: J4.16, U1.86 (PK3)
/CLK: J3.4, U1.78 (PA0)
/DIN: J3.5, U1.77 (PA1)
/HF1_BTN: J5.7, U1.53 (PC0)
/HF1_LED: J4.8, U1.94 (PF3)
/HF2_BTN: J5.8, U1.54 (PC1)
/HF2_LED: J4.9, U1.93 (PF4)
/ILS_BTN: J5.17, U1.58 (PC5)
/ILS_LED: J4.13, U1.89 (PK0)
/MLS_BTN: J5.18, U1.59 (PC6)
/MLS_LED: J4.14, U1.88 (PK1)
/NAV_BTN: J5.15, U1.56 (PC3)
/NAV_LED: J4.11, U1.91 (PF6)
/PWM_IN: J4.3, U1.15 (PH3)
/PWR_ON: J5.9, U1.51 (PG0)
/RADIO_KHZ_LEFT: J5.1, U1.75 (PA3)
/RADIO_KHZ_RIGHT: J5.12, U1.73 (PA5)
/RADIO_MHZ_LEFT: J5.2, U1.74 (PA4)
/RADIO_MHZ_RIGHT: J5.13, U1.72 (PA6)
/SEL_LED: J4.17, U1.85 (PK4)
/STBY_LOAD: J3.6, U1.83 (PK6)
/VHF1_BTN: J5.4, U1.70 (PG2)
/VHF1_LED: J4.5, U1.97 (PF0)
/VHF2_BTN: J5.5, U1.63 (PJ0)
/VHF2_LED: J4.6, U1.96 (PF1)
/VHF3_BTN: J5.6, U1.64 (PJ1)
/VHF3_LED: J4.7, U1.95 (PF2)
/VOR_BTN: J5.16, U1.57 (PC4)
/VOR_LED: J4.12, U1.90 (PF7)
/XFER_BTN: J5.3, U1.71 (PA7)
GND: C1.2, C2.2, C3.2, C4.2, C5.2, C6.2, C7.2, C8.2, C9.2, J3.2, J4.2, J4.4, J4.18, J5.10, J5.11, J5.21, J5.22, S1.1, S1.2, U1.11 (GND), U1.32 (GND), U1.62 (GND), U1.81 (GND), U1.99 (GND); also elsewhere on the board
MISO: U1.22 (PB3); also elsewhere on the board
MOSI: U1.21 (PB2); also elsewhere on the board
unnamed: C7.1, U1.98 (AREF)
unnamed: C9.1, U1.34 (XTAL1), XT16MHz1.1
unnamed: C8.1, U1.33 (XTAL2), XT16MHz1.2
RESET: C6.1, R1.2, S1.3, U1.30 (~RESET); also elsewhere on the board
RXD: U1.2 (PE0); also elsewhere on the board
SCK: U1.20 (PB1); also elsewhere on the board
TXD: U1.3 (PE1); also elsewhere on the board
VIN: C1.1, C2.1, C3.1, C4.1, C5.1, R1.1, U1.10 (VCC), U1.31 (VCC), U1.61 (VCC), U1.80 (VCC), U1.100 (AVCC); also elsewhere on the board

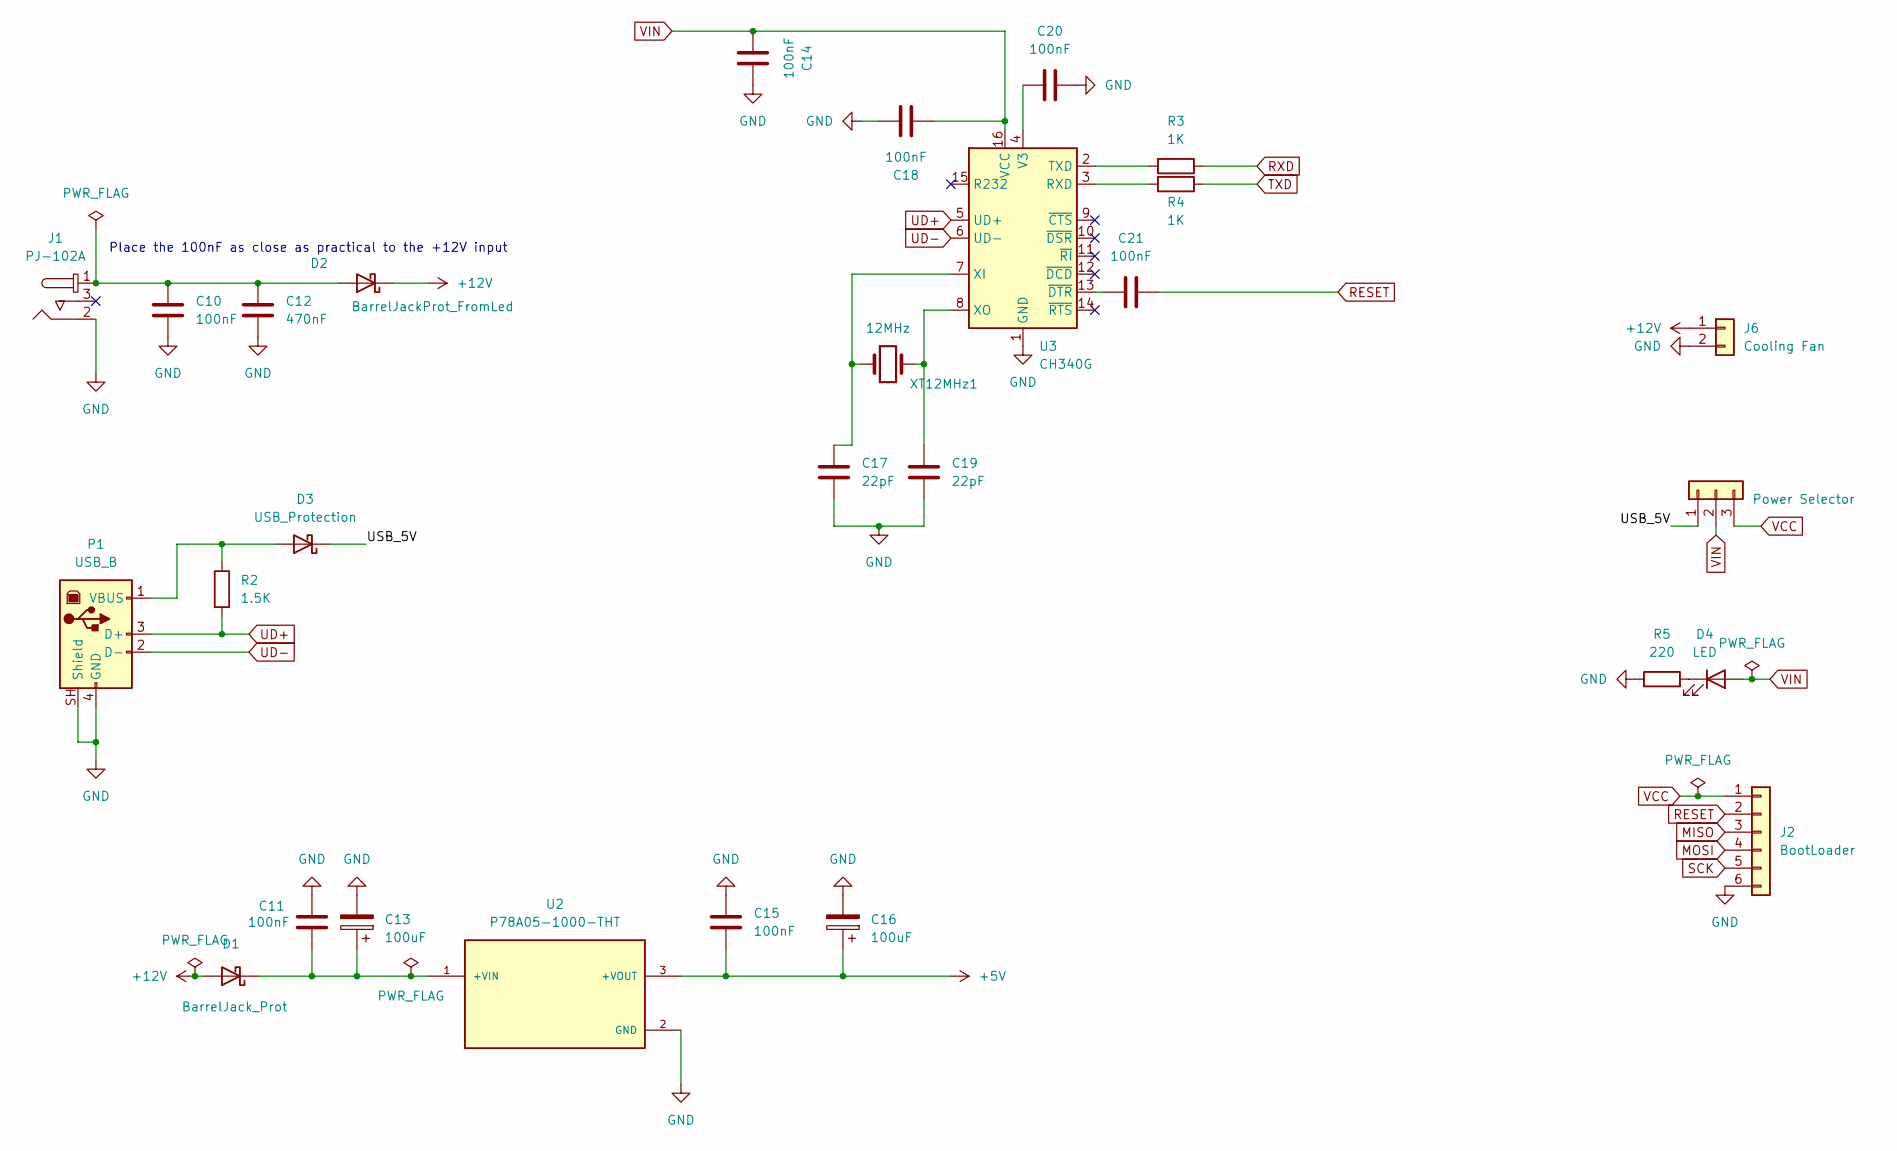
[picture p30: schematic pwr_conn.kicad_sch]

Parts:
C10, C11, C14, C15, C18, C20, C21: 100nF; C_1206_3216Metric_Pad1.33x1.80mm_HandSolder
C12: 470nF; C_1206_3216Metric_Pad1.33x1.80mm_HandSolder
C13, C16: 100uF; C_Elec_6.3x7.7
C17, C19: 22pF; C_1206_3216Metric_Pad1.33x1.80mm_HandSolder
D1: BarrelJack_Prot; D_SMA
D2: BarrelJackProt_FromLed; D_SMA
D3: USB_Protection; D_SMA
D4: LED; LED_1206_3216Metric_Pad1.42x1.75mm_HandSolder
J1: PJ-102A; Barrel_Jack_5.5mmODx2.1mmID_PJ-102A; MPN PJ-102A; Digi-Key_PN CP-102A-ND
J2: BootLoader; PinHeader_1x06_P2.54mm_Vertical
J6: Cooling Fan; PinHeader_1x02_P2.54mm_Vertical
JP1: Power Selector; PinHeader_1x03_P2.54mm_Vertical
P1: USB_B; USB_B_OST_USB-B1HSxx_Horizontal
R2: 1.5K; R_1206_3216Metric_Pad1.30x1.75mm_HandSolder
R3, R4: 1K; R_1206_3216Metric_Pad1.30x1.75mm_HandSolder
R5: 220; R_1206_3216Metric_Pad1.30x1.75mm_HandSolder
U2: P78A05-1000-THT; CONV_P78A05-1000; PARTREV 1.0
U3: CH340G; SOIC-16_3.9x9.9mm_P1.27mm
XT12MHz1: 12MHz; Crystal_SMD_5032-2Pin_5.0x3.2mm_HandSoldering

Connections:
+5V: C15.2, C16.1, U2.3 (+VOUT); also elsewhere on the board
+12V: D1.2 (A), D2.1 (K), J6.1; also elsewhere on the board
/PowerConnectors/USB_5V: D3.1 (K), JP1.1
GND: C10.2, C11.1, C12.2, C13.2, C14.2, C15.1, C16.2, C17.1, C18.2, C19.1, C20.2, J1.2, J2.6, J6.2, P1.4 (GND), P1.SH (Shield), R5.1, U2.2 (GND), U3.1 (GND); also elsewhere on the board
MISO: J2.3; also elsewhere on the board
MOSI: J2.4; also elsewhere on the board
unnamed: C11.2, C13.1, D1.1 (K), U2.1 (+VIN)
unnamed: C10.1, C12.1, D2.2 (A), J1.1
unnamed: D3.2 (A), P1.1 (VBUS), R2.1
unnamed: D4.1 (K), R5.2
unnamed: R4.2, U3.3 (RXD)
unnamed: R3.2, U3.2 (TXD)
unnamed: C20.1, U3.4 (V3)
unnamed: C17.2, U3.7 (XI), XT12MHz1.1
unnamed: C19.2, U3.8 (XO), XT12MHz1.2
unnamed: C21.1, U3.13 (~DTR)
RESET: C21.2, J2.2; also elsewhere on the board
RXD: R3.1; also elsewhere on the board
SCK: J2.5; also elsewhere on the board
TXD: R4.1; also elsewhere on the board
UD+: P1.3 (D+), R2.2, U3.5 (UD+)
UD-: P1.2 (D-), U3.6 (UD-)
VCC: J2.1, JP1.3
VIN: C14.1, C18.1, D4.2 (A), JP1.2, U3.16 (VCC); also elsewhere on the board

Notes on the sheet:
Place the 100nF as close as practical to the +12V input

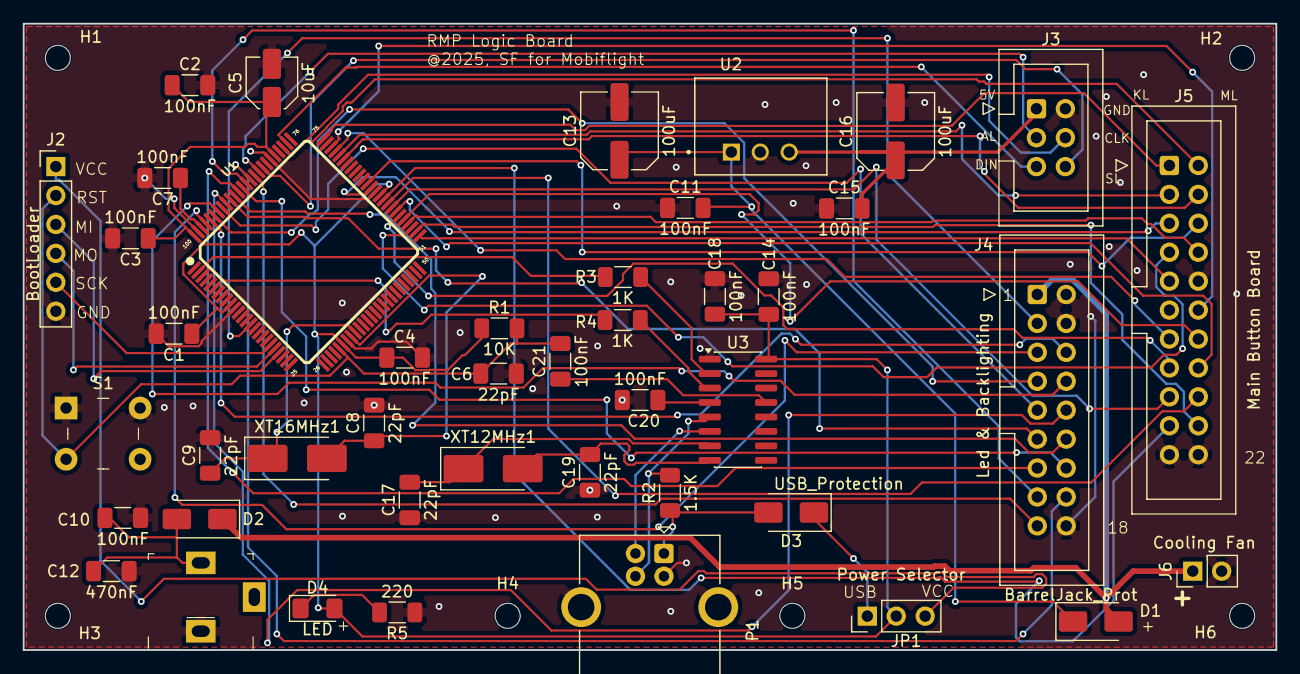
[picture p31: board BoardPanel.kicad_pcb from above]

Board: 2 copper layers, 110.0 x 55.0 mm, 50 parts (0 on the bottom side), 63 nets.

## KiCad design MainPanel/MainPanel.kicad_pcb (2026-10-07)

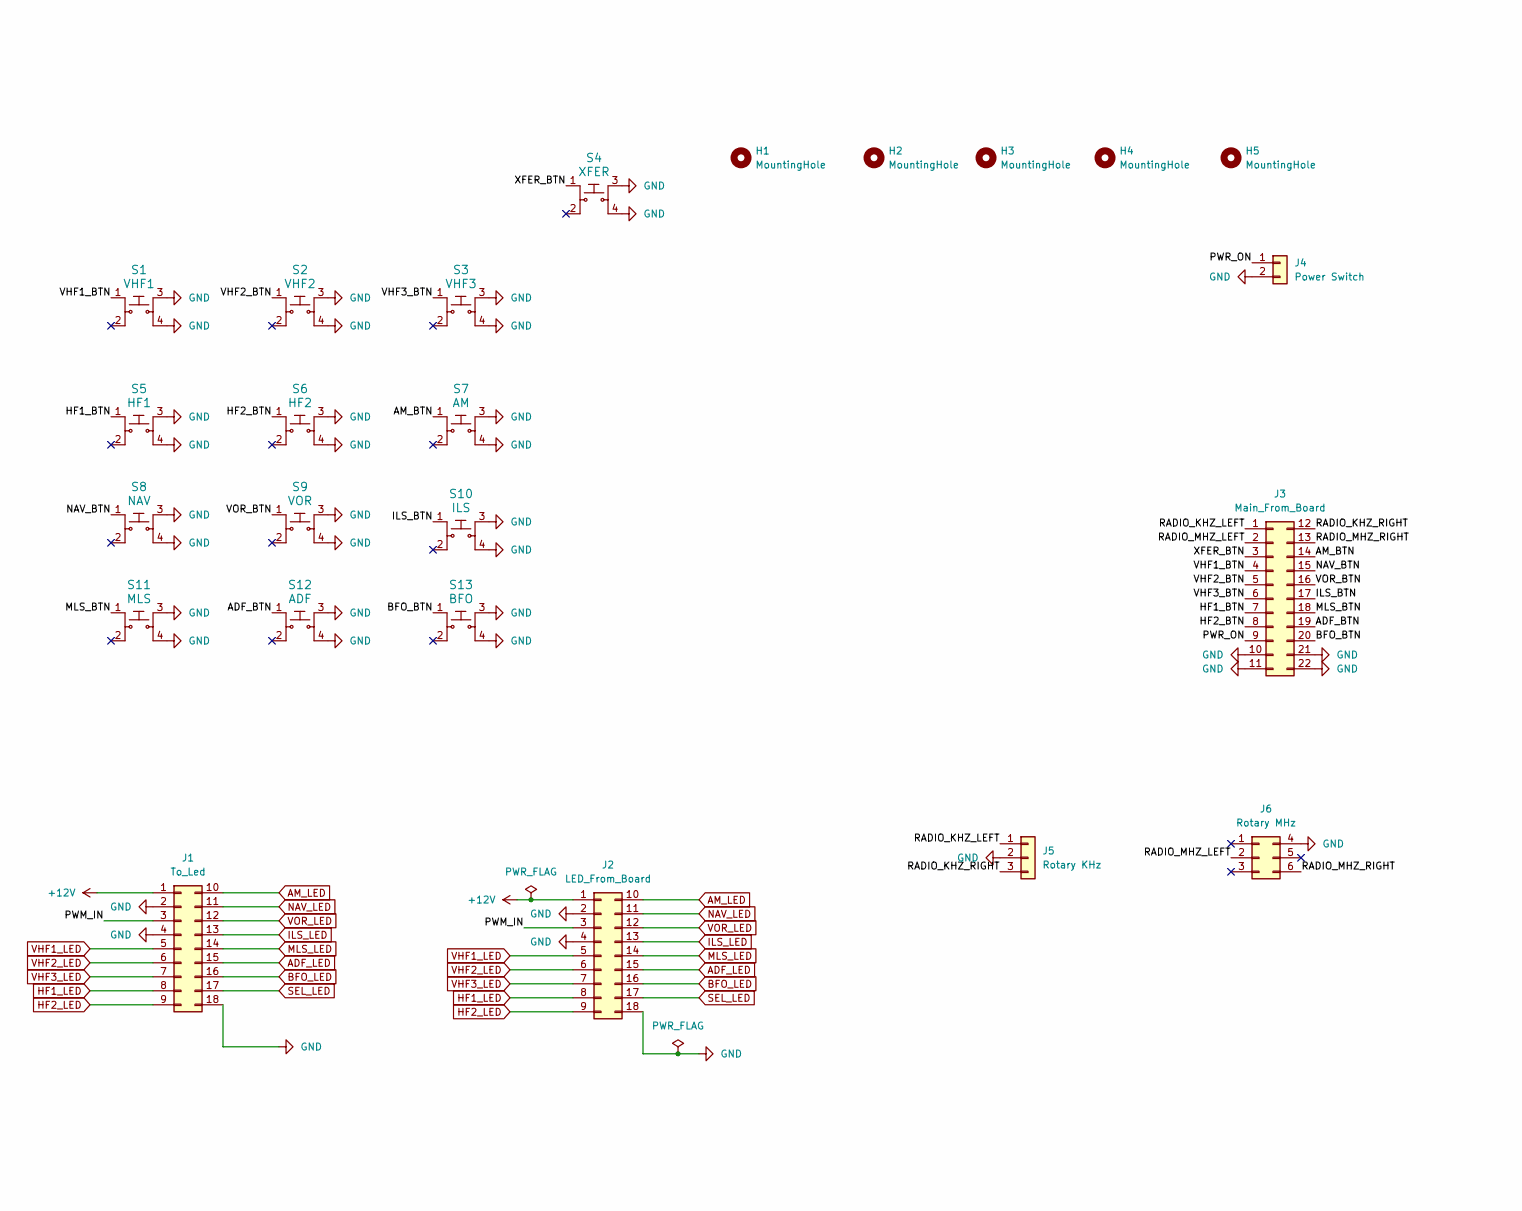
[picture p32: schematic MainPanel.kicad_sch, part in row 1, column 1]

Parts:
H1, H2, H3, H4, H5: MountingHole; MountingHole_2.5mm
J1: To_Led; PinSocket_2x09_P2.54mm_Vertical
J2: LED_From_Board; PinHeader_2x09_P2.54mm_Vertical
J3: Main_From_Board; PinHeader_2x11_P2.54mm_Vertical
J4: Power Switch; PinHeader_1x02_P2.54mm_Vertical
J5: Rotary KHz; PinSocket_1x03_P2.54mm_Vertical
J6: Rotary MHz; PinSocket_2x03_P2.54mm_Vertical
S1: VHF1; Switch_Tactile_THT_6x6mm_MJTP1230; MPN MJTP1230; Digi-Key_PN 679-2428-ND
S2: VHF2; Switch_Tactile_THT_6x6mm_MJTP1230; MPN MJTP1230; Digi-Key_PN 679-2428-ND
S3: VHF3; Switch_Tactile_THT_6x6mm_MJTP1230; MPN MJTP1230; Digi-Key_PN 679-2428-ND
S4: XFER; Switch_Tactile_THT_6x6mm_MJTP1230; MPN MJTP1230; Digi-Key_PN 679-2428-ND
S5: HF1; Switch_Tactile_THT_6x6mm_MJTP1230; MPN MJTP1230; Digi-Key_PN 679-2428-ND
S6: HF2; Switch_Tactile_THT_6x6mm_MJTP1230; MPN MJTP1230; Digi-Key_PN 679-2428-ND
S7: AM; Switch_Tactile_THT_6x6mm_MJTP1230; MPN MJTP1230; Digi-Key_PN 679-2428-ND
S8: NAV; Switch_Tactile_THT_6x6mm_MJTP1230; MPN MJTP1230; Digi-Key_PN 679-2428-ND
S9: VOR; Switch_Tactile_THT_6x6mm_MJTP1230; MPN MJTP1230; Digi-Key_PN 679-2428-ND
S10: ILS; Switch_Tactile_THT_6x6mm_MJTP1230; MPN MJTP1230; Digi-Key_PN 679-2428-ND
S11: MLS; Switch_Tactile_THT_6x6mm_MJTP1230; MPN MJTP1230; Digi-Key_PN 679-2428-ND
S12: ADF; Switch_Tactile_THT_6x6mm_MJTP1230; MPN MJTP1230; Digi-Key_PN 679-2428-ND
S13: BFO; Switch_Tactile_THT_6x6mm_MJTP1230; MPN MJTP1230; Digi-Key_PN 679-2428-ND

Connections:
+12V: J1.1, J2.1
/ADF_BTN: J3.19, S12.1
/AM_BTN: J3.14, S7.1
/BFO_BTN: J3.20, S13.1
/HF1_BTN: J3.7, S5.1
/HF2_BTN: J3.8, S6.1
/ILS_BTN: J3.17, S10.1
/MLS_BTN: J3.18, S11.1
/NAV_BTN: J3.15, S8.1
/PWM_IN: J1.3, J2.3
/PWR_ON: J3.9, J4.1
/RADIO_KHZ_LEFT: J3.1, J5.1
/RADIO_KHZ_RIGHT: J3.12, J5.3
/RADIO_MHZ_LEFT: J3.2, J6.2
/RADIO_MHZ_RIGHT: J3.13, J6.6
/VHF1_BTN: J3.4, S1.1
/VHF2_BTN: J3.5, S2.1
/VHF3_BTN: J3.6, S3.1
/VOR_BTN: J3.16, S9.1
/XFER_BTN: J3.3, S4.1
ADF_LED: J1.15, J2.15
AM_LED: J1.10, J2.10
BFO_LED: J1.16, J2.16
GND: J1.2, J1.4, J1.18, J2.2, J2.4, J2.18, J3.10, J3.11, J3.21, J3.22, J4.2, J5.2, J6.4, S1.3, S1.4, S2.3, S2.4, S3.3, S3.4, S4.3, S4.4, S5.3, S5.4, S6.3, S6.4, S7.3, S7.4, S8.3, S8.4, S9.3, S9.4, S10.3, S10.4, S11.3, S11.4, S12.3, S12.4, S13.3, S13.4; also elsewhere on the board
HF1_LED: J1.8, J2.8
HF2_LED: J1.9, J2.9
ILS_LED: J1.13, J2.13
MLS_LED: J1.14, J2.14
NAV_LED: J1.11, J2.11
SEL_LED: J1.17, J2.17
VHF1_LED: J1.5, J2.5
VHF2_LED: J1.6, J2.6
VHF3_LED: J1.7, J2.7
VOR_LED: J1.12, J2.12

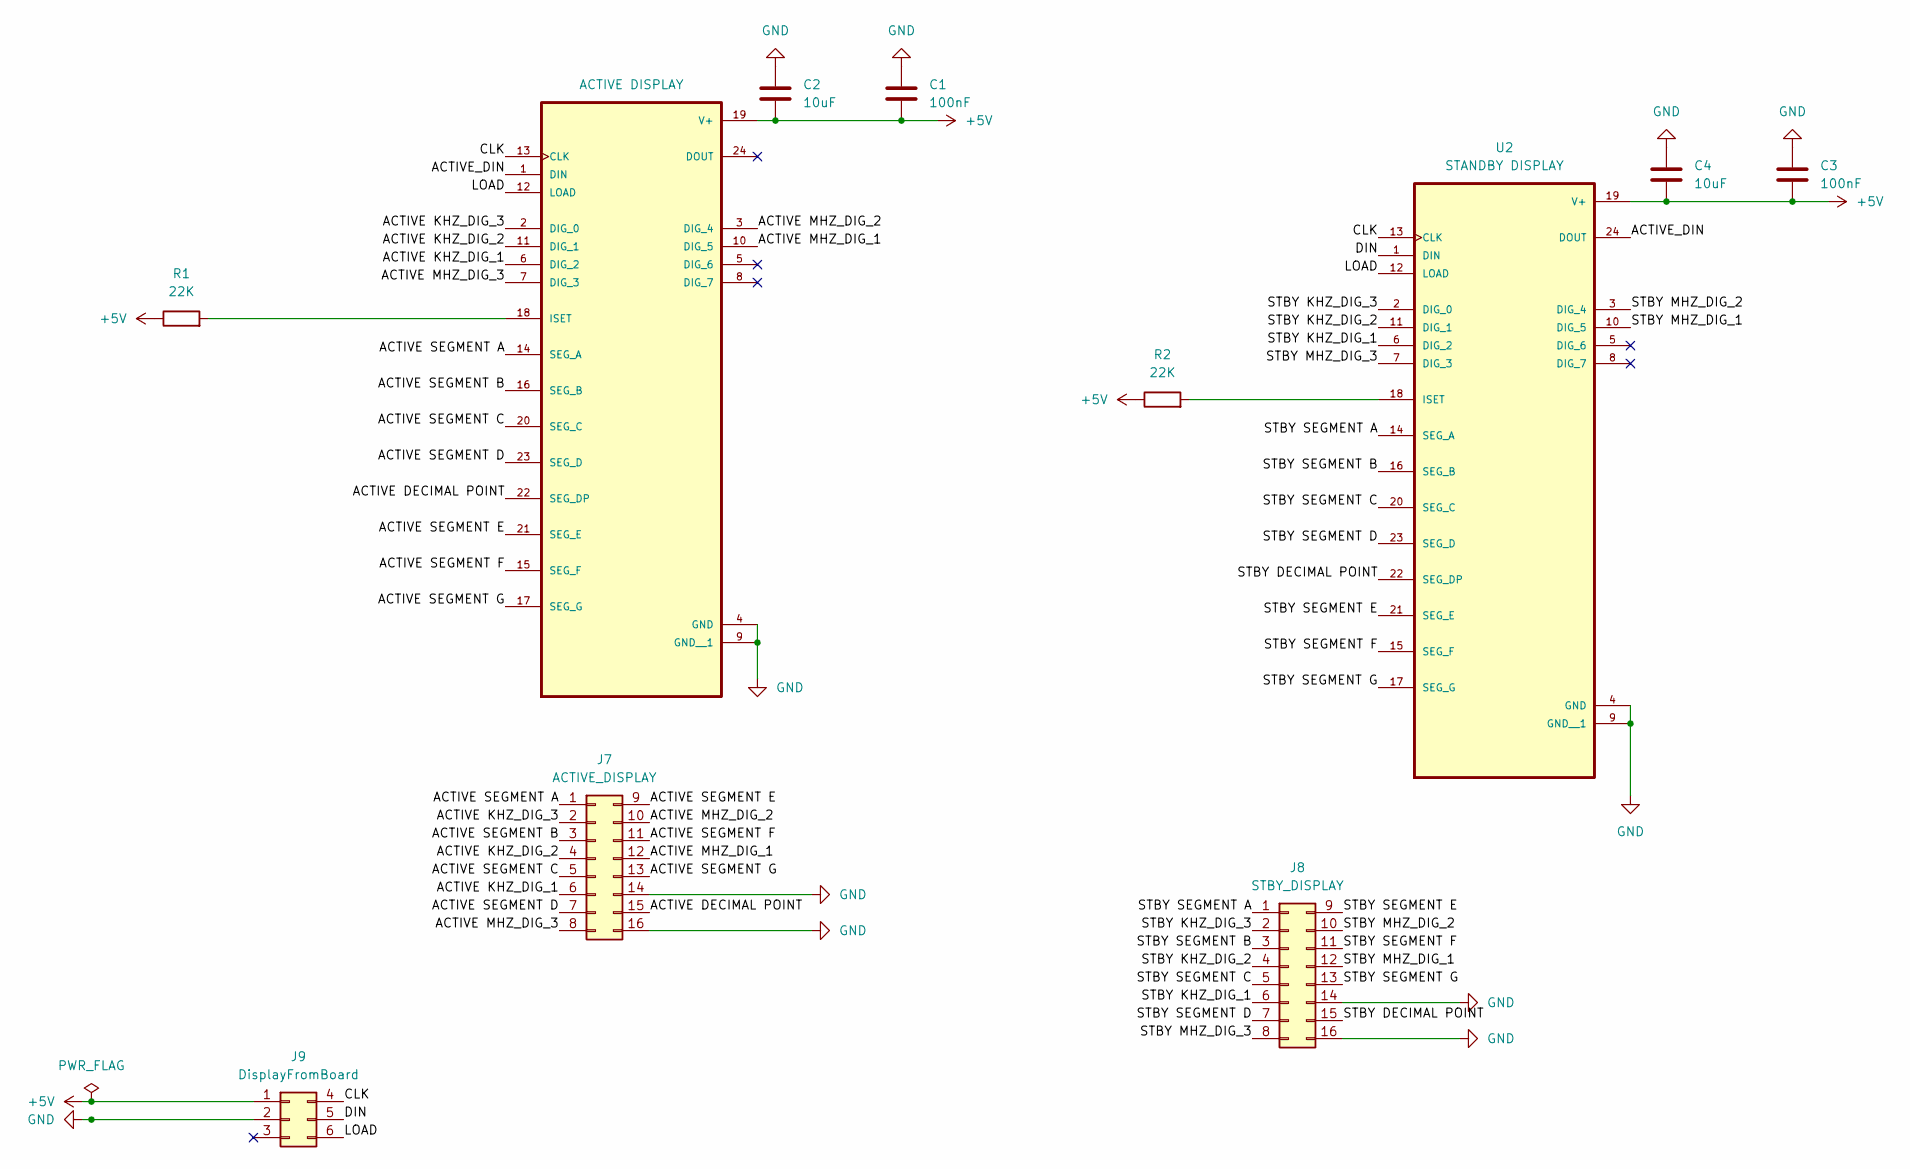
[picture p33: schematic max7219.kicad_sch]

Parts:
C1, C3: 100nF; C_1206_3216Metric
C2, C4: 10uF; C_1206_3216Metric
J7: ACTIVE_DISPLAY; PinHeader_2x08_P2.54mm_Vertical
J8: STBY_DISPLAY; PinHeader_2x08_P2.54mm_Vertical
J9: DisplayFromBoard; PinHeader_2x03_P2.54mm_Vertical
R1, R2: 22K; R_1206_3216Metric
U1: ACTIVE DISPLAY; SOIC127P1032X265-24N
U2: STANDBY DISPLAY; SOIC127P1032X265-24N

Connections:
+5V: C1.2, C2.2, C3.2, C4.2, J9.1, R1.1, R2.1, U1.19 (V+), U2.19 (V+)
/Max7219 Displays/ACTIVE DECIMAL POINT: J7.15, U1.22 (SEG_DP)
/Max7219 Displays/ACTIVE KHZ_DIG_1: J7.6, U1.6 (DIG_2)
/Max7219 Displays/ACTIVE KHZ_DIG_2: J7.4, U1.11 (DIG_1)
/Max7219 Displays/ACTIVE KHZ_DIG_3: J7.2, U1.2 (DIG_0)
/Max7219 Displays/ACTIVE MHZ_DIG_1: J7.12, U1.10 (DIG_5)
/Max7219 Displays/ACTIVE MHZ_DIG_2: J7.10, U1.3 (DIG_4)
/Max7219 Displays/ACTIVE MHZ_DIG_3: J7.8, U1.7 (DIG_3)
/Max7219 Displays/ACTIVE SEGMENT A: J7.1, U1.14 (SEG_A)
/Max7219 Displays/ACTIVE SEGMENT B: J7.3, U1.16 (SEG_B)
/Max7219 Displays/ACTIVE SEGMENT C: J7.5, U1.20 (SEG_C)
/Max7219 Displays/ACTIVE SEGMENT D: J7.7, U1.23 (SEG_D)
/Max7219 Displays/ACTIVE SEGMENT E: J7.9, U1.21 (SEG_E)
/Max7219 Displays/ACTIVE SEGMENT F: J7.11, U1.15 (SEG_F)
/Max7219 Displays/ACTIVE SEGMENT G: J7.13, U1.17 (SEG_G)
/Max7219 Displays/ACTIVE_DIN: U1.1 (DIN), U2.24 (DOUT)
/Max7219 Displays/CLK: J9.4, U1.13 (CLK), U2.13 (CLK)
/Max7219 Displays/DIN: J9.5, U2.1 (DIN)
/Max7219 Displays/LOAD: J9.6, U1.12 (LOAD), U2.12 (LOAD)
/Max7219 Displays/STBY DECIMAL POINT: J8.15, U2.22 (SEG_DP)
/Max7219 Displays/STBY KHZ_DIG_1: J8.6, U2.6 (DIG_2)
/Max7219 Displays/STBY KHZ_DIG_2: J8.4, U2.11 (DIG_1)
/Max7219 Displays/STBY KHZ_DIG_3: J8.2, U2.2 (DIG_0)
/Max7219 Displays/STBY MHZ_DIG_1: J8.12, U2.10 (DIG_5)
/Max7219 Displays/STBY MHZ_DIG_2: J8.10, U2.3 (DIG_4)
/Max7219 Displays/STBY MHZ_DIG_3: J8.8, U2.7 (DIG_3)
/Max7219 Displays/STBY SEGMENT A: J8.1, U2.14 (SEG_A)
/Max7219 Displays/STBY SEGMENT B: J8.3, U2.16 (SEG_B)
/Max7219 Displays/STBY SEGMENT C: J8.5, U2.20 (SEG_C)
/Max7219 Displays/STBY SEGMENT D: J8.7, U2.23 (SEG_D)
/Max7219 Displays/STBY SEGMENT E: J8.9, U2.21 (SEG_E)
/Max7219 Displays/STBY SEGMENT F: J8.11, U2.15 (SEG_F)
/Max7219 Displays/STBY SEGMENT G: J8.13, U2.17 (SEG_G)
GND: C1.1, C2.1, C3.1, C4.1, J7.14, J7.16, J8.14, J8.16, J9.2, U1.4 (GND), U1.9 (GND__1), U2.4 (GND), U2.9 (GND__1); also elsewhere on the board
unnamed: R1.2, U1.18 (ISET)
unnamed: R2.2, U2.18 (ISET)

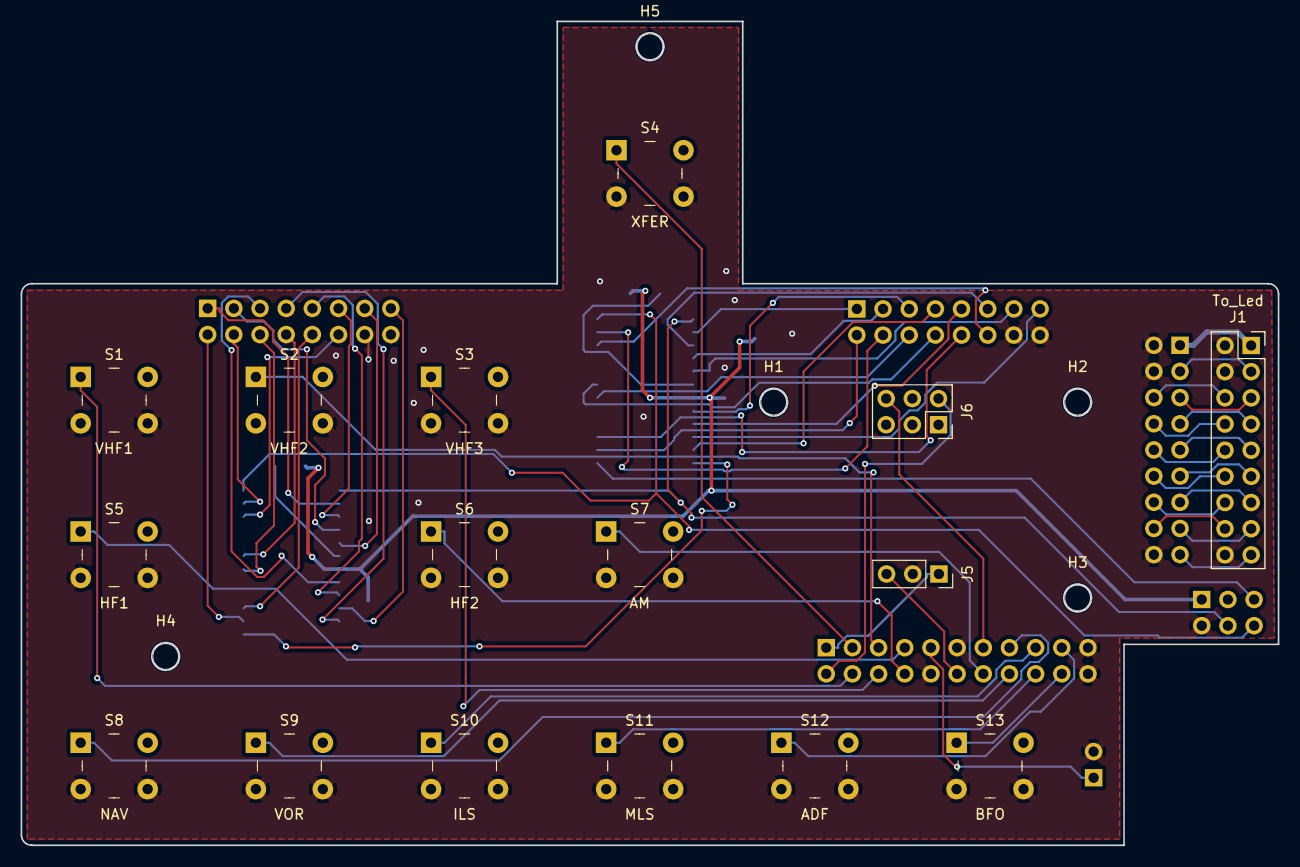
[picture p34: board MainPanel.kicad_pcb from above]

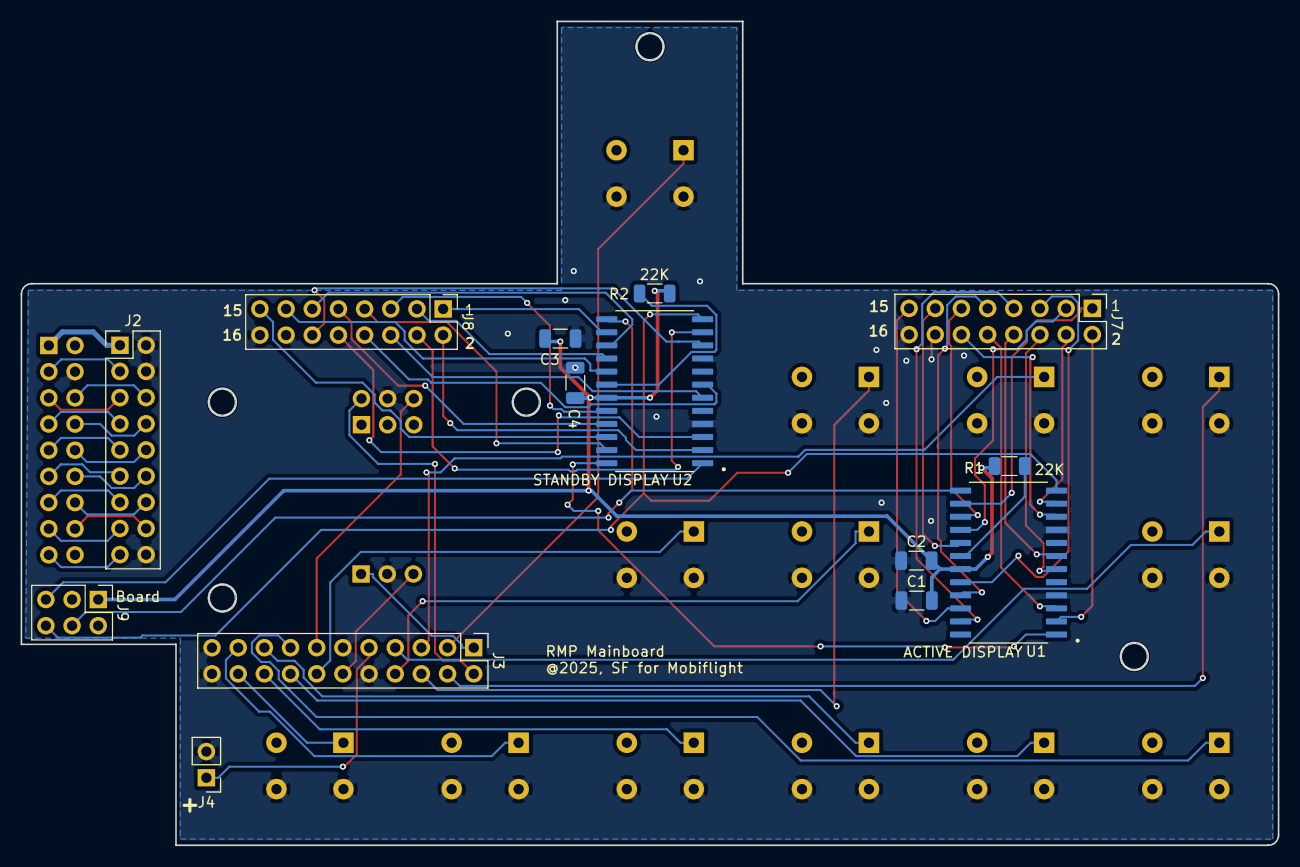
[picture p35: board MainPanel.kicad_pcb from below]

Board: 2 copper layers, 122.0 x 79.9 mm, 35 parts (14 on the bottom side), 69 nets.

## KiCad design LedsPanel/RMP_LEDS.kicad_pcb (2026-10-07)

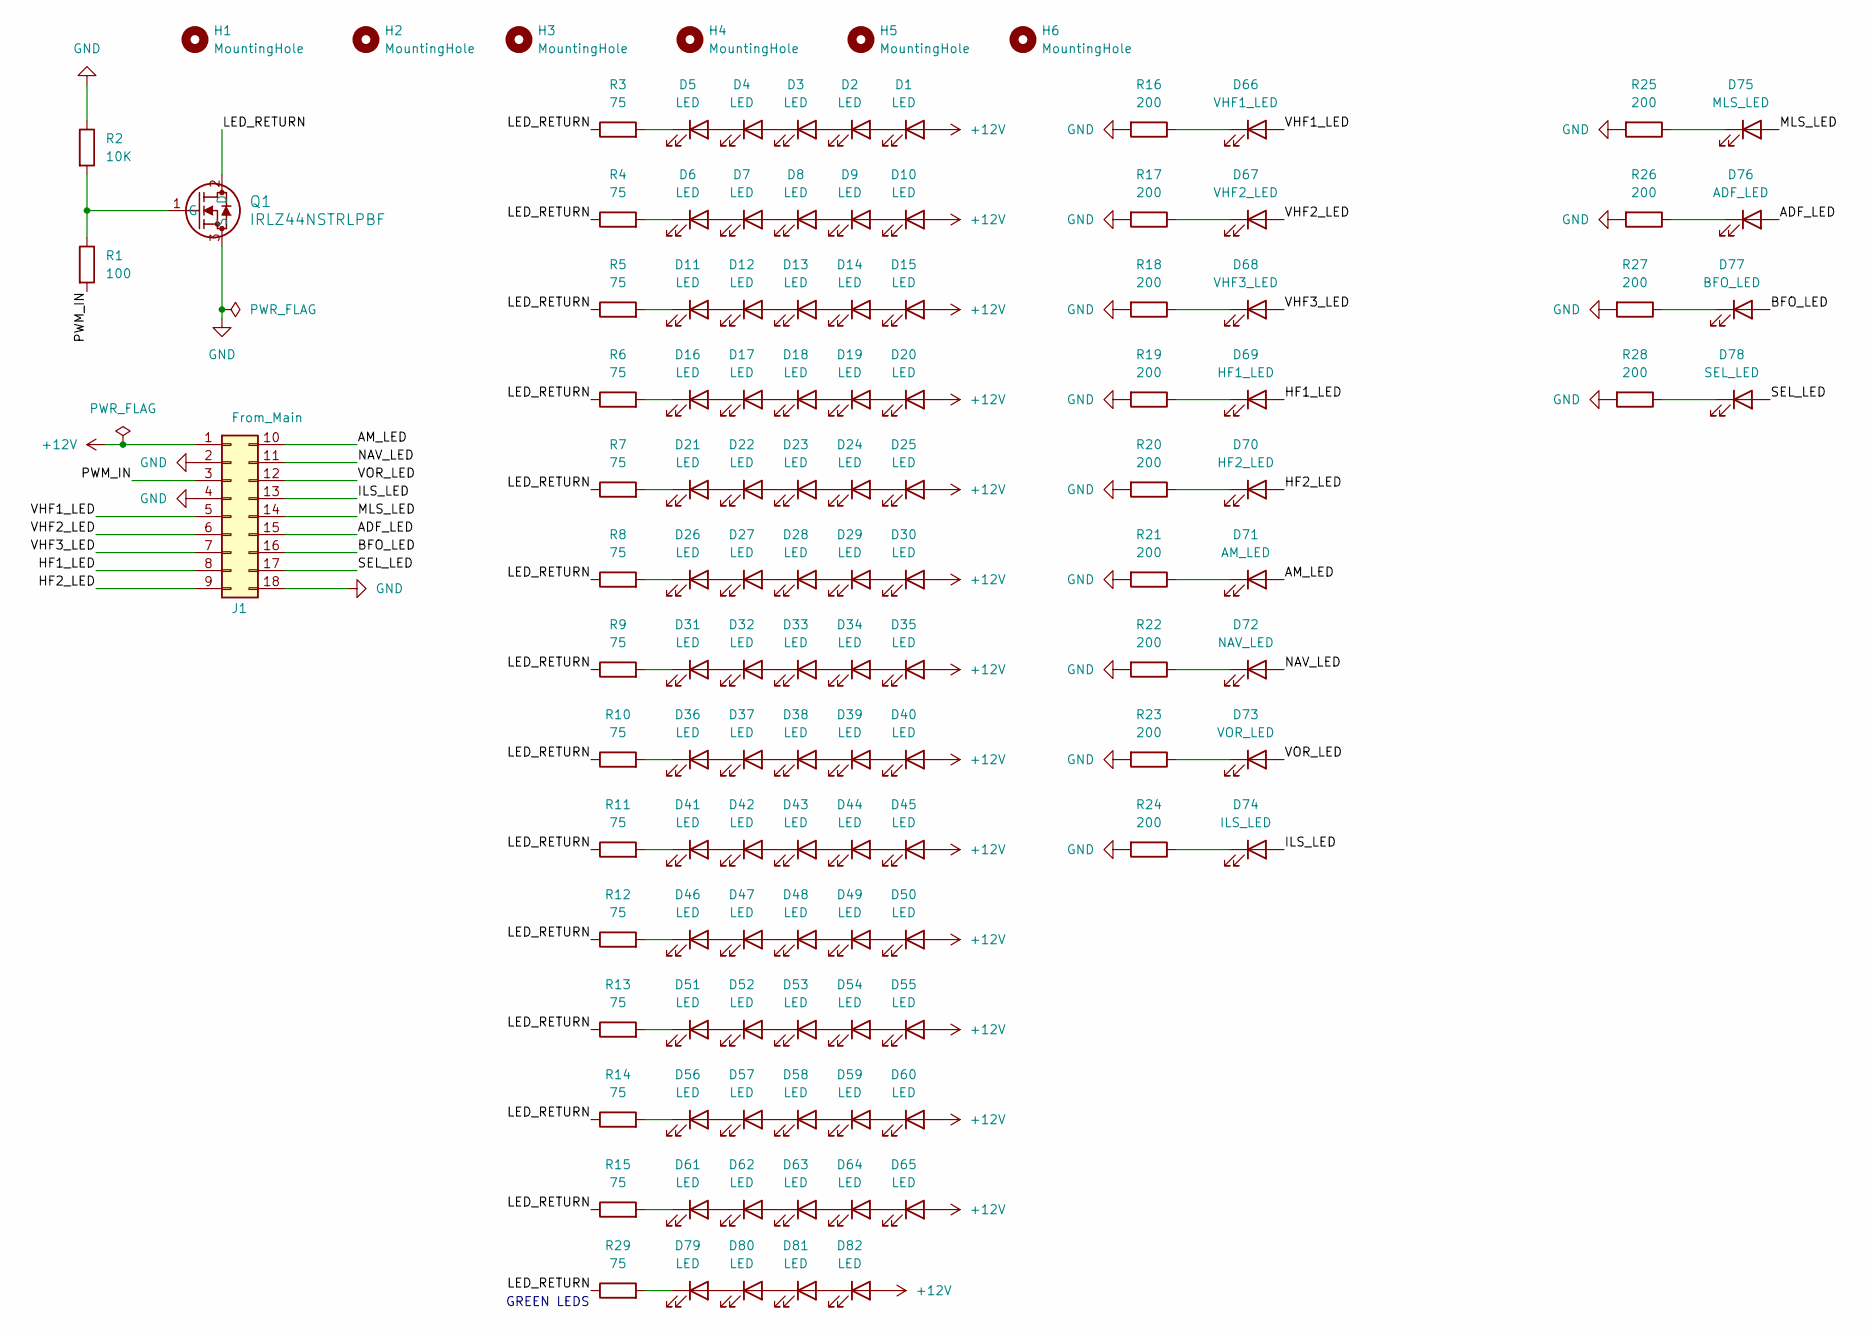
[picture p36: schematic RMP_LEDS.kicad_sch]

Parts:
D1, D2, D3, D4, D5, D6, D7, D8, D9, D10, D11, D12, D13, D14, D15, D16, D17, D18, D19, D20, D21, D22, D23, D24, D25, D26, D27, D28, D29, D30, D31, D32, D33, D34, D35, D36, D37, D38, D39, D40, D41, D42, D43, D44, D45, D46, D47, D48, D49, D50, D51, D52, D53, D54, D55, D56, D57, D58, D59, D60, D61, D62, D63, D64, D65, D79, D80, D81, D82: LED; LED_0805_2012Metric_Pad1.15x1.40mm_HandSolder
D66: VHF1_LED; LED_D3.0mm_FlatTop
D67: VHF2_LED; LED_D3.0mm_FlatTop
D68: VHF3_LED; LED_D3.0mm_FlatTop
D69: HF1_LED; LED_D3.0mm_FlatTop
D70: HF2_LED; LED_D3.0mm_FlatTop
D71: AM_LED; LED_D3.0mm_FlatTop
D72: NAV_LED; LED_D3.0mm_FlatTop
D73: VOR_LED; LED_D3.0mm_FlatTop
D74: ILS_LED; LED_D3.0mm_FlatTop
D75: MLS_LED; LED_D3.0mm_FlatTop
D76: ADF_LED; LED_D3.0mm_FlatTop
D77: BFO_LED; LED_D3.0mm_FlatTop
D78: SEL_LED; LED_D3.0mm_FlatTop
H1, H2, H3, H4, H5, H6: MountingHole; MountingHole_2.7mm_M2.5
J1: From_Main; PinHeader_2x09_P2.54mm_Vertical
Q1: IRLZ44NSTRLPBF; NMOSGDS_D2PAK_INF
R1: 100; R_1206_3216Metric_Pad1.30x1.75mm_HandSolder
R2: 10K; R_1206_3216Metric_Pad1.30x1.75mm_HandSolder
R3, R4, R5, R6, R7, R8, R9, R10, R11, R12, R13, R14, R15, R29: 75; R_1206_3216Metric_Pad1.30x1.75mm_HandSolder
R16, R17, R18, R19, R20, R21, R22, R23, R24, R25, R26, R27, R28: 200; R_1206_3216Metric_Pad1.30x1.75mm_HandSolder

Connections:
+12V: D1.2 (A), D10.2 (A), D15.2 (A), D20.2 (A), D25.2 (A), D30.2 (A), D35.2 (A), D40.2 (A), D45.2 (A), D50.2 (A), D55.2 (A), D60.2 (A), D65.2 (A), D82.2 (A), J1.1
/ADF_LED: D76.2 (A), J1.15
/AM_LED: D71.2 (A), J1.10
/BFO_LED: D77.2 (A), J1.16
/HF1_LED: D69.2 (A), J1.8
/HF2_LED: D70.2 (A), J1.9
/ILS_LED: D74.2 (A), J1.13
/LED_RETURN: Q1.2 (D), R3.1, R4.1, R5.1, R6.1, R7.1, R8.1, R9.1, R10.1, R11.1, R12.1, R13.1, R14.1, R15.1, R29.1
/MLS_LED: D75.2 (A), J1.14
/NAV_LED: D72.2 (A), J1.11
/PWM_IN: J1.3, R1.2
/SEL_LED: D78.2 (A), J1.17
/VHF1_LED: D66.2 (A), J1.5
/VHF2_LED: D67.2 (A), J1.6
/VHF3_LED: D68.2 (A), J1.7
/VOR_LED: D73.2 (A), J1.12
GND: J1.2, J1.4, J1.18, Q1.3 (S), R2.1, R16.2, R17.2, R18.2, R19.2, R20.2, R21.2, R22.2, R23.2, R24.2, R25.2, R26.2, R27.2, R28.2
unnamed: D1.1 (K), D2.2 (A)
unnamed: D2.1 (K), D3.2 (A)
unnamed: D3.1 (K), D4.2 (A)
unnamed: D4.1 (K), D5.2 (A)
unnamed: D5.1 (K), R3.2
unnamed: D6.2 (A), D7.1 (K)
unnamed: D6.1 (K), R4.2
unnamed: D7.2 (A), D8.1 (K)
unnamed: D8.2 (A), D9.1 (K)
unnamed: D9.2 (A), D10.1 (K)
unnamed: D11.2 (A), D12.1 (K)
unnamed: D11.1 (K), R5.2
unnamed: D12.2 (A), D13.1 (K)
unnamed: D13.2 (A), D14.1 (K)
unnamed: D14.2 (A), D15.1 (K)
unnamed: D16.2 (A), D17.1 (K)
unnamed: D16.1 (K), R6.2
unnamed: D17.2 (A), D18.1 (K)
unnamed: D18.2 (A), D19.1 (K)
unnamed: D19.2 (A), D20.1 (K)
unnamed: D21.2 (A), D22.1 (K)
unnamed: D21.1 (K), R7.2
unnamed: D22.2 (A), D23.1 (K)
unnamed: D23.2 (A), D24.1 (K)
unnamed: D24.2 (A), D25.1 (K)
unnamed: D26.2 (A), D27.1 (K)
unnamed: D26.1 (K), R8.2
unnamed: D27.2 (A), D28.1 (K)
unnamed: D28.2 (A), D29.1 (K)
unnamed: D29.2 (A), D30.1 (K)
unnamed: D31.2 (A), D32.1 (K)
unnamed: D31.1 (K), R9.2
unnamed: D32.2 (A), D33.1 (K)
unnamed: D33.2 (A), D34.1 (K)
unnamed: D34.2 (A), D35.1 (K)
unnamed: D36.2 (A), D37.1 (K)
unnamed: D36.1 (K), R10.2
unnamed: D37.2 (A), D38.1 (K)
unnamed: D38.2 (A), D39.1 (K)
unnamed: D39.2 (A), D40.1 (K)
unnamed: D41.2 (A), D42.1 (K)
unnamed: D41.1 (K), R11.2
unnamed: D42.2 (A), D43.1 (K)
unnamed: D43.2 (A), D44.1 (K)
unnamed: D44.2 (A), D45.1 (K)
unnamed: D46.2 (A), D47.1 (K)
unnamed: D46.1 (K), R12.2
unnamed: D47.2 (A), D48.1 (K)
unnamed: D48.2 (A), D49.1 (K)
unnamed: D49.2 (A), D50.1 (K)
unnamed: D51.2 (A), D52.1 (K)
unnamed: D51.1 (K), R13.2
unnamed: D52.2 (A), D53.1 (K)
unnamed: D53.2 (A), D54.1 (K)
unnamed: D54.2 (A), D55.1 (K)
unnamed: D56.2 (A), D57.1 (K)
unnamed: D56.1 (K), R14.2
unnamed: D57.2 (A), D58.1 (K)
unnamed: D58.2 (A), D59.1 (K)
unnamed: D59.2 (A), D60.1 (K)
unnamed: D61.2 (A), D62.1 (K)
unnamed: D61.1 (K), R15.2
unnamed: D62.2 (A), D63.1 (K)
unnamed: D63.2 (A), D64.1 (K)
unnamed: D64.2 (A), D65.1 (K)
unnamed: D66.1 (K), R16.1
unnamed: D67.1 (K), R17.1
unnamed: D68.1 (K), R18.1
unnamed: D69.1 (K), R19.1
unnamed: D70.1 (K), R20.1
unnamed: D71.1 (K), R21.1
unnamed: D72.1 (K), R22.1
unnamed: D73.1 (K), R23.1
unnamed: D74.1 (K), R24.1
unnamed: D75.1 (K), R25.1
unnamed: D76.1 (K), R26.1
unnamed: D77.1 (K), R27.1
unnamed: D78.1 (K), R28.1
unnamed: D79.2 (A), D80.1 (K)
unnamed: D79.1 (K), R29.2
unnamed: D80.2 (A), D81.1 (K)
unnamed: D81.2 (A), D82.1 (K)
unnamed: Q1.1 (G), R1.1, R2.2

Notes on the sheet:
GREEN LEDS

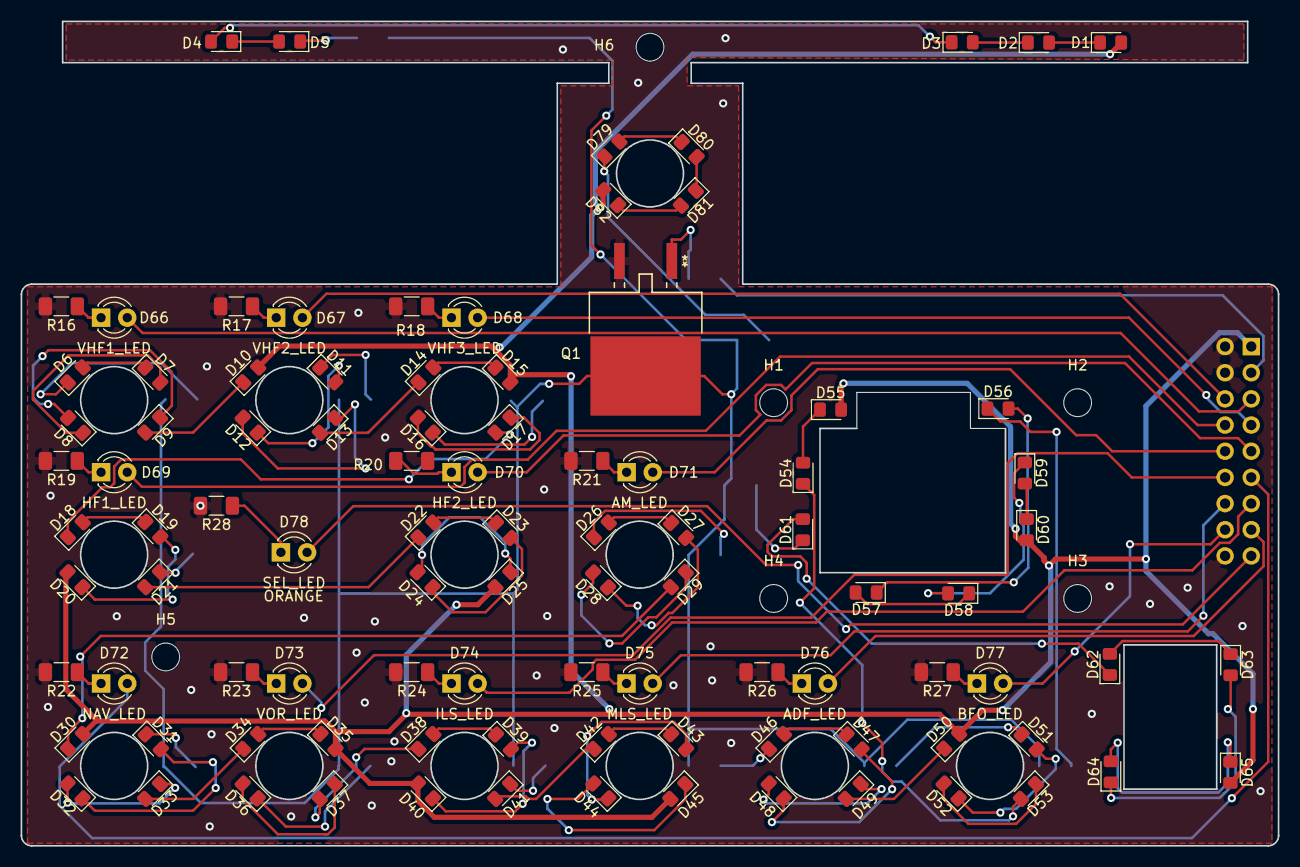
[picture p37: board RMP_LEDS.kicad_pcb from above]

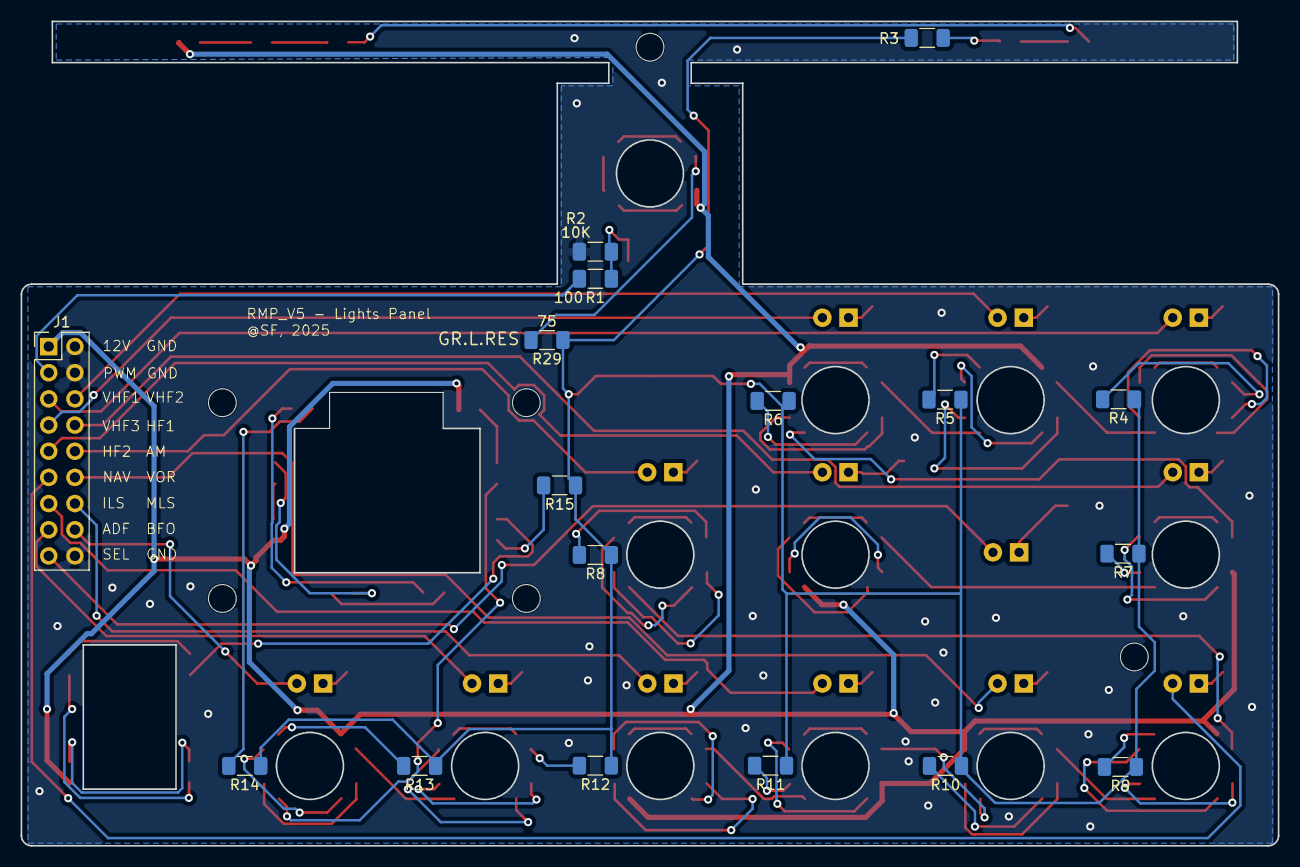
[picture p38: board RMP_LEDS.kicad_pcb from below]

Board: 2 copper layers, 122.0 x 80.0 mm, 119 parts (17 on the bottom side), 100 nets.

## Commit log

2026-10-05 Start tracking the RMP V5 as it stands
    The four KiCad 9 projects (BoardPanel, MainPanel, LedsPanel, 7Segments),
    the FreeCAD 1.1 sources and the STL files, unchanged. Backups, recovery
    copies, board STEP exports and fabrication output stay local.
    [7segments.kicad_pcb, 7segments.kicad_sch, BoardPanel.kicad_pcb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]
2026-10-05 Migrate the four boards to KiCad 10 format
    Resaved with kicad-cli upgrade: schematics 20250114 -> 20260306, boards
    20241229 -> 20260206. The projects no longer open in KiCad 9. The two
    sub-sheets, pwr_conn and max7219, are not saved by upgrading their root,
    so they were upgraded on their own.
    The diff is large but carries no design change. Checked against the
    KiCad 9 files, board by board:
    netlist same components, references, values and footprints;
    same nets with the same nodes
    copper F.Cu, B.Cu and Edge.Cuts plot to the same geometry
    ERC 2 / 4 / 3 / 17 violations, unchanged
    DRC same violations by category, 0 unconnected
    The DRC entries are s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
    [7segments.kicad_pcb, 7segments.kicad_sch, BoardPanel.kicad_pcb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]
2026-10-05 Move the boards to the top level, as in the other panels
    BoardPanel, MainPanel, LedsPanel and 7Segments leave "Kicad Files" and
    sit at the root of the repository, like the mainboard and section boards
    of the overhead panel. The shared part library will go beside them, in
    Libraries/. Pure renames, no file content changed.
    [7segments.kicad_pcb, 7segments.kicad_sch, BoardPanel.kicad_pcb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]
2026-10-05 Bring the custom parts into Libraries/, shared by all four boards
    Six parts came from libraries that live only on the author's PC (SF
    Library, IRLZ44N, P78A05-1000, Custom_Footprints, PCM_SFLibrary and the
    Digi-Key PCM libraries). Their 3D models pointed at a KiCad 9 3rdparty
    folder that no longer exists, so the boards rendered without them.
    They now sit in Libraries/ under one nickname, RMP, as the overhead
    panel does with OVHD:
    RMP.kicad_sym MAX7219CWGT, IRLZ44NSTRLPBF, P78A05-1000, PJ-102A,
    1825910-6, MJTP1230, taken from the schematic caches,
    i.e. the symbols the boards were drawn with
    RMP.pretty CONV_P78A05-1000, SOIC127P1032X265-24N,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
    [BoardPanel.kicad_pcb, BoardPanel.kicad_sch, MainPanel.kicad_pcb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]
2026-10-07 Chain the two MAX7219 on the MainPanel, as the built unit is wired
    The schematic had both drivers on the MCU's DIN with a LOAD each (D67 for
    the Active, D68 for the Standby) and both DOUT unconnected. The board in
    use only works because two wires were added by hand: LOAD to LOAD, and
    the Standby's DOUT to the Active's DIN. MobiFlight drives it as one LED
    module of two devices on CS D68: connector 1 is the Standby, the first
    in the chain, connector 2 the Active.
    The design now matches:
    DIN J9 pin 5 (D23) -> U2 (Standby) pin 1 only
    ACTIVE_DIN U2 pin 24 (DOUT) -> U1 (Active) pin 1
    LOAD J9 pin 6 (D68) -> U1 and U2 pin 12
    J9 pin 3 (D67) no longer used, flagged no-conn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
    [MainPanel.kicad_pcb, max7219.kicad_sch]
2026-10-07 Clear the ERC errors and the real DRC findings on all four boards
    7Segments
    - J5 used Conn_02x08_Top_Bottom_Shielded on an IDC header with no shield
    pad: ERC flagged the SH pin, DRC a net conflict. It is now the plain
    Conn_02x08_Top_Bottom, like J7/J8 on the MainPanel; pins 1-16 sit at
    the same points, so nothing else moved.
    - GND had no driver: PWR_FLAG added.
    BoardPanel
    - P1 read "USB_C_Plug_USB2.0" on a USB-B connector: value now USB_B.
    - +5V had no driver: pin 3 (+VOUT) of the P78A05 symbol is now a power
    output, in the schematic and in Libraries/RMP.kicad_sym. A PWR_FLAG
    there would clash with the pin.
    MainPanel
    - A stray no-connect flag and a second PWR_FLAG on the same net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
    [7segments.kicad_pcb, 7segments.kicad_sch, BoardPanel.kicad_pcb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]
2026-10-07 Update symbols and footprints from the KiCad 10 libraries
    Run in KiCad: Update Footprints from Library and Update PCB from
    Schematic on all four boards, and Update Symbol from Library on P1 of
    the BoardPanel only. Updating every symbol there would have reset the
    ATmega's footprint field to the library default, as it did on the FCU.
    ERC 0 on all four boards
    DRC 0 on BoardPanel, LedsPanel and MainPanel; 15 silkscreen-
    clipped-by-mask warnings left on the 7Segments
    parity 0 everywhere; 0 unconnected
    Every pad keeps its position and its net (IPC-D-356 compared before and
    after on all 775 pads). Copper plots to the same coordinates. The only
    netlist change is the on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
    [7segments.kicad_pcb, BoardPanel.kicad_pcb, BoardPanel.kicad_sch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]
2026-10-07 Document the RMP: a readme for the panel and for each board
    Readme.md replaces the V3 one: what V5 is, the four boards and how they
    are cabled, how to build one, the MobiFlight board config and pin map,
    and the known issues.
    Each board folder gets a readme with its size, fixing, connectors and
    pinouts, assembly notes, and three images rendered by KiCad from the board
    file: a raytraced 3D view, the top and the bottom, cropped on a
    transparent background. The MainPanel readme explains the corrected
    display chain and the two wires a first-run board needs.
    SF_RMP/SF RMP.mfmc is the board config the built unit runs, with the
    module renamed SF RMP. LICENSE is the GPLv3, as before.
    Co-Authored-B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
